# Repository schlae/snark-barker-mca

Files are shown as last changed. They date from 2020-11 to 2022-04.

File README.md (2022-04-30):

# Snark Barker MCA - A Sound Blaster Compatible for Micro Channel Computers!

Do you desperately want a sound card for playing games on your Micro Channel-based IBM PS/2 computer--a system designed for serious business purposes? Do you not want to pay the ludicrous auction prices for the rare Sound Blaster MCV cards? Well, despair no longer: the Snark Barker MCA has arrived!

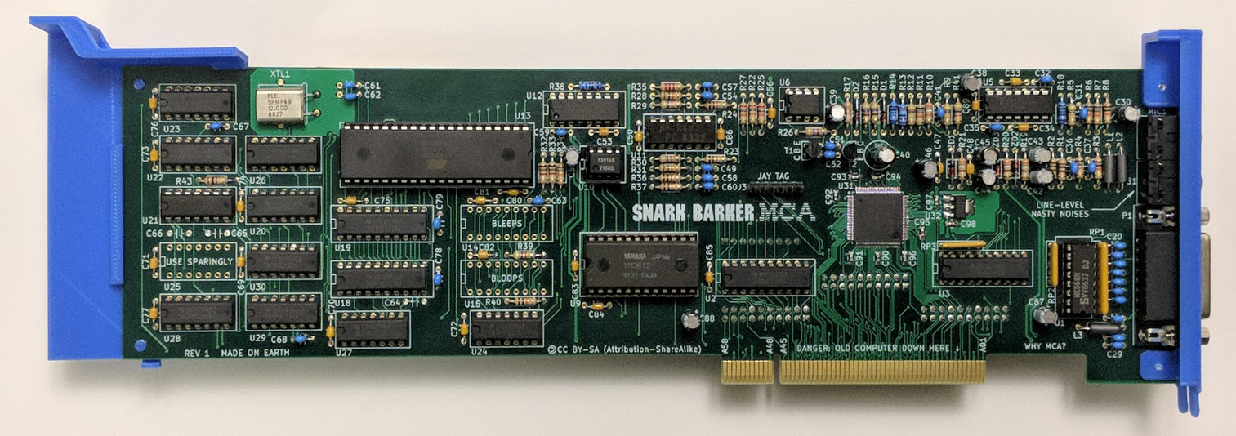
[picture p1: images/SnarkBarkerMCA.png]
Snark Barker MCA Photo


The Snark Barker MCA is a Sound Blaster-compatible sound card designed specifically for computers that use the Micro Channel bus. It supports Ad Lib synthesis, digital sound playback and recording, a standard PC joystick, and SB MIDI.

All of the components are readily available. In the bill of materials, Mouser part numbers are listed where available. The Yamaha synthesis chips may be obtained from a variety of sources in China, but they are not guaranteed to work, so I recommend getting 1 or 2 extras just in case. The same goes for the NE558. Note: A user reports that a Signetics NE558 with a date code of 8825VI that seems to be commonly available from China does not actually work. If you can't find any working 558 chips, try building [my replacement that uses four 555 chips](https://oshpark.com/shared_projects/zHGURt7g).

[Schematic](https://github.com/schlae/snark-barker-mca/blob/master/SnarkBarkerMCA.pdf)

[Bill of Materials](https://github.com/schlae/snark-barker-mca/blob/master/SnarkBarkerMCA.csv)

Please note that the 0.1" header pins are *not* listed on the BOM. They are standard breakaway headers. Headers J2, J4, J5, and J6 are optional and only useful for people who want to connect a logic analyzer to the bus for CPLD debugging.

The CMS chips U14 and U15 should not be installed since CMS functionality is not implemented at this time. Other devices listed as "DNI" are to be left empty with no component soldered in place.

Logic chips are all specified as AHCT, but ALS or ACT may also be used. Do not use LS or HCT devices, particularly for U2, since Micro Channel is a much faster bus than ISA and this logic is not quite fast enough to meet the timing margins. Bipolar families like F or S devices use excessive amounts of power but can be used in a pinch.

[Fab Files](https://github.com/schlae/snark-barker-mca/blob/master/fab/SnarkBarkerMCA-Rev2.zip)

## Fabrication Notes
This is a 4-layer board. The order of the two inner layers does not matter, but typically it goes F\_Cu, In1\_Cu, In2\_Cu, and B\_Cu. The board dimensions are 11.5 inches (292.1mm) by 3.475 inches (88.265mm).

When ordering the board, you **must** specify a card edge bevel of 20 degrees (details of the bevel are included in the Dwgs.User layer). This is **not** optional! The contacts in the Micro Channel socket are easily bent if you attempt to insert a card with no bevel. [Don't believe me? See this page.](https://www.ardent-tool.com/RS6000/RS6000_9-K.html#ECA265)

Ideally you should use selective gold plating (hard gold) for the edge fingers, but this can get expensive for small orders. ENIG will work but the gold will rub off fairly quickly.

For the soldermask color, pick whatever you want!

## Assembly Notes
I recommend soldering the CPLD (U31), the voltage regulator (U32), and the associated surface mount capacitors before you solder in the remaining components. You can do this by hand with a pencil iron or you can use a reflow process, but be aware that the board is too long to fit in the small hobbyist reflow ovens.

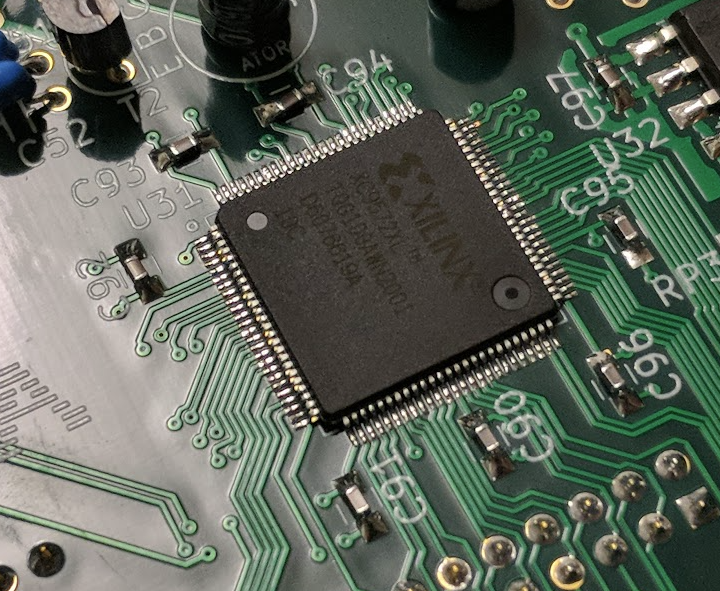
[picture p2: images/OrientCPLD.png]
Photo showing pin 1 alignment of CPLD


***Be sure the CPLD is soldered in the right way around! Compare it with my photo of the card to be sure you have it right!***

Inspect the CPLD's solder joints carefully with a microscope to make sure you don't have any bad connections or solder bridges. This can save you a lot of grief later on.

Install sockets for the Yamaha chips U9 and U10 in case you get one that doesn't work and need to replace it.

## Bracket
MCA brackets are no longer available. You have a few options:
- Remove the brackets from an existing card, like a token ring card or something common
- 3D print the bracket
- Use the card without a bracket at all

If you want to print your own brackets, here are STL files of the front panel bracket and the rear bracket.

[Front bracket](https://github.com/schlae/snark-barker-mca/blob/master/mech/SnarkBarkerMCABracket3D.STL)

[Rear bracket](https://github.com/schlae/snark-barker-mca/blob/master/mech/MCARearBracket.STL)

For best results, use high quality filament and a layer height of 0.16mm or better. If you print using blue filament, the color will match the original IBM brackets.

The front bracket should be oriented so that the front face of the bracket is facing towards the bed of the printer. The rear bracket should be oriented so its large flat spot (parallel to the card) faces the bed.

To secure the bracket to the card, you need two screws, and you have several options:
- 2-56 pan-head screws, 3/16" long, McMaster Carr 91772A076 or similar. These work but aren't the strongest.
- Number 2 thread forming screws, 3/16" long, McMaster Carr 99461A710 or similar. These should grip the plastic tightly (TODO: untested).
- There may be equivalent metric options but this requires experimentation. Please let me know if you find a fastener that works well.

## The Firmware
There are two ways to get a programmed 80C51 chip for the Snark Barker MCA. One is to purchase a SB 2.0 DSP chip from China and put it in a 44-PLCC to 40-DIP adapter. This works fine and provides the largest feature set.

Another option is to buy a blank Atmel 89S51 (as listed in the BOM) and program it with [this HEX file](https://github.com/schlae/snark-barker/blob/master/firmware/sb.hex).

## CPLD Notes
The Snark Barker MCA uses a CPLD (Complex Programmable Logic Device) to interface between the Micro Channel bus and the rest of the card's digital logic. This CPLD implements port IO, interrupts, DMA, and the card setup and POS (Programmable Option Select) systems.

The CPLD must be programmed with the bitstream before you can use the card.
[You can find the bitstream here.](https://github.com/schlae/snark-barker-mca/blob/master/verilog/mcsb.jed)

I've had good luck using the Linux command line program 'xc3sprog' with a FTDI FT2232H Mini Module [datasheet here](https://www.ftdichip.com/Support/Documents/DataSheets/Modules/DS_FT2232H_Mini_Module.pdf).

Wiring for the FT2232H mini module:

| Point 1 | Point 2 | Description |
| --- | --- | --- |
| CN2 pin 1  | CN2 pin 11 | V3V3 to VIO strap |
| CN3 pin 1  | CN3 pin 3 | VBUS to VCC strap |
| CN2 pin 3  | CN3 pin 12 | V3V3 to VIO strap (2) |
| CN2 pin 5  | JTAG cable pin 6 | V3V3 to Snark Barker (optional) |
| CN2 pin 2  | JTAG cable pin 5 | GND |
| CN2 pin 7  | JTAG cable pin 4 | AD0, aka TCK |
| CN2 pin 9  | JTAG cable pin 3 | AD2, aka TDO |
| CN2 pin 10 | JTAG cable pin 2 | AD1, aka TDI |
| CN2 pin 12 | JTAG cable pin 1 | AD3, aka TMS |

You need to provide external power to the Snark Barker through the 3.3V wire on the programming header. The optional wire does this, or you can use a bench supply.

I obtained xc3sprog [here](https://github.com/matrix-io/xc3sprog). You can compile and run this program on a Raspberry Pi to use the Pi GPIO lines instead of the FTDI mini module. In my case, I chose to patch it (TBD) to remove references to the Pi GPIO library and ran it on a regular Linux PC.

Using the FTDI mini module, programming is quite simple. Connect the cable to
the assembled Snark Barker board, then run the following command. You can do this with just the CPLD, programming header, and surface mount capacitors--there's no need to have any of the other components soldered in place for this step.

`xc3sprog -c ftdi -v mcadlib.jed`

If you run into issues with the cable not being detected, check your udev rules.
In theory you could run xc3sprog as root, but that's bad practice. ;)

### Building the CPLD Project
If you're feeling particularly masochistic, you can try building the CPLD project using the Xilinx ISE Webpack tools. Because the ISE Webpack only supports Ubuntu 14.7, it's simplest to run the program from a Docker container. I use [docker-xilinx](https://github.com/jimmo/docker-xilinx).

### How the CPLD Works
This isn't meant to be an exhaustive tutorial on how Micro Channel works ([you can find a tutorial here](https://github.com/schlae/mca-tutorial)). Functions provided by the CPLD include:
- Card setup and POS
- Address decoding logic
- Bus logic interface to the YM3812
- Wait state logic for the YM3812 interface
- Interrupt logic
- DMA state machine including arbitration logic

Each card implements several 8-bit registers (POS registers). Two of these registers are fixed and implement the 16-bit card ID value, which is how the BIOS and the reference disk software identify the card. The remaining POS registers can be used for any configuration-related function and are designed to replace configuration jumpers. The meanings of each register bit are up to the card designer, with the exception of a reserved bit that is used by the BIOS to enable or disable a card; this way, the BIOS can resolve conflicts automatically. Typically POS register bits control IO and memory address assignments, IRQ lines, and so forth.

The CPLD implements the two required ID registers as well as two additional POS registers. The first contains only a single bit -- the card enable signal. The second register controls the IO port setting, the IRQ and DMA channel settings, and the joystick port enable bit.

When you add a new card to a MCA bus system, the BIOS detects the new card and requires you to run the reference disk configuration program. This program searches for an ADF file associated with the new card. The ADF file is human-readable text that tells the BIOS which I/O address, IRQ, etc match up with each POS register bit. The reference disk program uses this information to find a configuration for all the cards in the computer so that none of them conflict with each other. When it's done, it writes the raw POS register values along with the card ID values to the battery-backed SRAM on the motherboard.

## Compatibility
The Snark Barker MCA has been tested on some models of PS/2. More to be added as
people provide test reports.

| Computer | Model | CPU | Compatible ? |
| --- | --- | --- | --- |
| IBM PS/2 Model 50Z | 8550-031 | 80286-10 | Yes |
| IBM PS/2 Model 55SX | 8555-X31 | 486SXLC2 | Yes |
| IBM PS/2 Model 56  | 9556-KB6 | 80486SLC2-50 | Partial(1) |
| IBM PS/2 Model 70  | 8570-E21 | 80386DX-16 | Yes |
| IBM PS/2 Model 70  | 8570-B21 | 80486DX2-50  | Yes(1) |
| IBM PS/2 Model P70 | 8573-061 | 80386DX-20 | Yes |
| IBM PS/2 Model P75 | 8573-401 | 486DX2-66 | Yes(5) |
| IBM PS/2 Model 80  | 8580-071 | 80386DX-16 | Yes(4) |
| IBM PS/2 Model 95  | 8595 | 486DX2-50 | Yes(1) |
| IBM PS/2 Model 95  | 9595 | Pentium-90 | Yes(3) |
| NCR System 3400 | 3433 | 486DX2-66 | Yes |
| NCR System 3400 | 3421 | 386SX-20 | Issues(2) |

Note 1: See the *Machine Specific Notes* section below for more details about this configuration.

Note 2: Some problems reported with the NCR 3421 possibly due to a conflict with the onboard SCSI. Further investigation is needed.

Note 3: The Ad Lib detection routine used by some games is reported not to work

Note 4: There is one report of the Plaid Bib (the ancestor to this card) behaving erratically in this model of PS/2. However I have not observed any issues with the Snark Barker MCA.

Note 5: Machine has LAN Adapter/A installed.

If you build the card and try it out, please let me know how it went. **Be sure to give me the full part number of your computer along with any installed options (3rd-party planar, memory cards, etc).** If you're located in Silicon Valley, you could also loan me (or even give me!) a computer not on this list and I will test for compatibility myself.

## Machine Specific Notes

### IBM PS/2 Model 56 486SLC2 (9556-KB6)
Configuration: No cards installed.

The joystick port conflicts with the SCSI host that is built into the planar and must be disabled.

### IBM PS/2 Model 70 486 (8570-B21)
The configuration tested included
- 8MB RAM (on the planar)
- ESDI hard drive with DOS 6.22 and Windows 3.11 installed
- Buslogic BT640A SCSI card
- IBM XGA-2 video card

Although not fully understood, this configuration experiences what appear to be IRQ conflicts. The Micro Channel bus allows IRQ sharing, but not all software supports this correctly, so it may be related to that. "Doom" only works when using IRQ2. A workaround is to replace the default DOS4GW DOS extender with the DOS32A extender; this allows IRQ5 and IRQ7 to work correctly.

The Windows Sound Blaster driver crashes unless it is replaced with the driver recommended by Creative Labs for the SB Pro MCV. "VDMAD.386" is in the SB Pro MCV driver pack.

```
Some PS/2 machines experience a "Bus timeout error" when running Windows
3.1 in enhanced mode.  If you have this problem, Copy VDMAD.386 to your 
WINDOWS\SYSTEM sub-directory and change the following line under the [386Enh]
section in your SYSTEM.INI file.
[386Enh]
;change this line
DEVICE=*VDMAD
;to this line
DEVICE=VDMAD.386
```

You can also fix it by first starting Windows in standard mode, `win /s`, exit, and then start Windows in enhanced mode `win` as you normally would.

### IBM PS/2 Model 95 486DX2-50 (8595)
The joystick seems to conflict with something else and the setup program turns it off.

Getting Doom to run is slightly tricky and requires a hack. It only worked when IRQ was set to 5 and DOS4GW was replaced with DOS32A, but this version doesn't properly initialize the sound card. The hack is this:
- Make a copy of DOOM.EXE: `copy doom.exe doom_p.exe`
- Apply the DOS32A patch: `sb /r doom_p.exe`
- Run the original first: `doom` and let it crash back to the DOS prompt.
- Run the patched executable: `doom_p`

## Installation
You will need the ADF (adapter description file) in order to set up the Snark Barker MCA on your Micro Channel computer.

[Snark Barker MCA ADF](https://github.com/schlae/snark-barker-mca/blob/master/@5085.ADF)

Place the file on a 3 1/2" floppy disk. After you install the card and boot
the computer, it will detect that a new card has been installed and prompt
you to insert the reference disk. Do this and follow the prompts. When the
setup utility asks you to insert the option disk, use the one that contains
the ADF file. After the setup utility configures the card, it will prompt
you to reboot the machine.

Plug your line-level audio amplifier input into the card's 3mm audio jack nearest the joystick port. The other audio jack above that one is for the microphone input.

Once that's finished, try out the Snark Barker MCA with your favorite game!

## Troubleshooting
Hoo boy, this one is a doozie. Someone once told me
> At Creative Labs tech support we would always get a sinking feeling whenever someone said they had a SoundBlaster MCA. Guaranteed at least a 45 minute call. Weekly average call time blown straight to hell.

Keep in mind that Micro Channel systems can be difficult to troubleshoot due to the large number of possible configurations and the varied implementations of the bus. Not all games will even work on some PS/2 systems even without a sound card!

Here are a few things to try out first before you starting really digging in:
- Is the CPLD soldered in correctly, with no solder bridges? Did you program it?
- Are there potentially bad or fake chips? Some users have reported issues with fake NE555s or fake 74ALS245 chips.
- Did you program and install the 8051 (DSP)?
- If the BIOS detects and installs the card, but you have issues with the audio, try removing all the expansion cards except for the Snark Barker
- Try running [SBDIAG](https://github.com/schlae/snark-barker/tree/master/sbdiag)

### Symptom-by-Symptom

**Computer will not boot at all, Computer boots but does not detect the card**

Suspect the CPLD. Check for bad solder joints. Is pin 1 oriented correctly? Compare it with the photo.

Did you use something other than a 74HCT245 or 74ALS245 for U2? Slower logic families can "crash the bus" and prevent the system from booting.

**Joystick doesn't function**

Is the joystick enabled? Run the setup program and navigate to "Change Configuration" and see if the joystick is on or off. The setup program may have turned it off due to a conflict with another card (Ethernet cards often like to use the joystick port location).

**No digitized sound. Digitized sounds play but are cut off**

It is possible that you have an IRQ conflict. Micro Channel allows for IRQ sharing and not all games support this correctly. Try changing the IRQ using the setup program's "Change Configuration" menu and see if that helps.

Since games implement Sound Blaster support in different ways, some programs may work and others may not!

**The card causes random errors with the hard disk, or other cards**

Do you have a legitimate 74ALS245, or is it fake? A user reported that swapping this part out with a legitimate one solved the problem for him.

### Troubleshooting for Engineers
If you have an HP logic analyzer, like a 1670 or 16700 series, you can connect three cables to the Snark Barker MCA using standard HP 01650-63203 termination adapters. The pin assignments are as follows:

| Pin |  J2 |  J4  |  J5 |
|-----|---|---|---|
| CLK | CMD | ADL  | PREEMPT  |
| D0  | BUSRESET  | A0 | DS16RTN  |
| D1  | M\_IO | A1 | CHRDYRTN |
| D2  | S0\_WRITE | A2 | MADE24 |
| D3  | S1\_READ  | A3 | CD\_DS16 |
| D4  | CD\_SETUP | A4 | TC |
| D5  | REFRESH | A5 | ARB/GNT  |
| D6  | CD\_SFDBK | A6 | CHCK |
| D7  | CD\_CHRDY | A7 | IRQ7 |
| D8  | DB0 | A8 | IRQ5 |
| D9  | DB1 | A9 | IRQ3 |
| D10 | DB2 | A10  | IRQ2 |
| D11 | DB3 | A11  | ARB3 |
| D12 | DB4 | A12  | ARB2 |
| D13 | DB5 | A13  | ARB1 |
| D14 | DB6 | A14  | ARB0 |
| D15 | DB7 | A15  | BURST |

Or, you can load [this configuration file](https://github.com/schlae/snark-barker-mca/blob/master/MCABASE._A) onto your HP analyzer and save a bunch of manual data entry. J2 goes to pod 1, J4 goes to pod 2, and J5 goes to pod 3.

An additional debug header, J6, brings out a few additional signals:

| Pin | J6 |
|-----|---|
| 1 | DBG1 (CPLD unassigned) |
| 2 | CLK\_14M318 (MCA bus clock) |
| 3 | DBG3 (CPLD unassigned) |
| 4 | DBG4 (CPLD unassigned) |
| 5 | DBG5 (CPLD unassigned) |
| 6 | DBG6 (CPLD unassigned) |
| 7 | DBG7 (CPLD unassigned) |
| 8 | SBHE (MCA bus signal) |
| 9 | GND |

## License
This work is licensed under a Creative Commons Attribution-ShareAlike 4.0
International License. See [https://creativecommons.org/licenses/by-sa/4.0/](https://creativecommons.org/licenses/by-sa/4.0/).

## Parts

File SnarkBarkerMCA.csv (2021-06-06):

Item | Qty | Reference(s) | Value | Footprint | Mouser
1 | 10 | C20, C21, C22, C23, C24, C25, C26, C27, C28, C29 | 0.01u | SoundBlaster:SB_C_DISC_200 | 810-FG28X7R1H103KNT0
2 | 11 | C30, C38, C39, C42, C43, C44, C45, C46, C55, C87, C88 | 10uF 16V | SoundBlaster:SB_C_RADIAL_75_150 | 667-ECA-1CM100I
3 | 7 | C31, C36, C37, C49, C54, C63, C78 | 1000p | SoundBlaster:SB_C_DISC_200 | 810-FG28X7R1H102KNT6
4 | 4 | C32, C35, C52, C79 | 330p | SoundBlaster:SB_C_DISC_200 | 810-FG28C0G1H331JNT6
5 | 24 | C33, C34, C47, C48, C50, C53, C56, C69, C70, C71, C72, C73, C74, C75, C76, C77, C80, C81, C82, C83, C84, C85, C86, C89 | 0.1u | SoundBlaster:SB_C_AXIAL_275 | 581-SA105E104M
6 | 1 | C40 | 100uF 16V | SoundBlaster:SB_C_RADIAL_100_320 | 667-ECA-1CM101I
7 | 2 | C41, C59 | 47p | SoundBlaster:SB_C_DISC_200 | 810-FG28C0G1H470JNT6
8 | 3 | C51, C58, C60 | 2200p | SoundBlaster:SB_C_DISC_200 | 810-FG28X7R1H222KNT6
9 | 1 | C57 | 4700p | SoundBlaster:SB_C_DISC_200 | 810-FG28C0G1H472JNT6
10 | 2 | C61, C62 | 30p | SoundBlaster:SB_C_DISC_200 | 810-FG28C0G1H270JNT6
11 | 3 | C64, C65, C66 | DNI | SoundBlaster:SB_C_DISC_200
12 | 1 | C67 | 470p | SoundBlaster:SB_C_DISC_200 | 810-FG28C0G1H471JNT6
13 | 1 | C68 | 270p | SoundBlaster:SB_C_DISC_200 | 810-FG28C0G1H271JNT0
14 | 9 | C90, C91, C92, C93, C94, C95, C96, C97, C98 | 1u | Passive:CAPC2012X55 | 187-CL21B105KAFNNNE
15 | 2 | D1, D2 | 1N4148 | SoundBlaster:SB_D_AXIAL_400 | 512-1N4148
16 | 2 | G1, G2 | logo1 | SoundBlasterMCA:Snark_BarkerMCA
17 | 1 | J1 | BUS_MCA | Conn:BUS_MCA
18 | 3 | J2, J4, J5 | HPLA_PORT | Pin_Headers:Pin_Header_Straight_2x10_Pitch2.54mm
19 | 1 | J3 | Conn_01x06 | Pin_Headers:Pin_Header_Straight_1x06_Pitch2.54mm
20 | 1 | J6 | DEBUG | Pin_Headers:Pin_Header_Straight_1x09_Pitch2.54mm
21 | 3 | L1, L2, L3 | BEAD | SoundBlaster:SB_L_AXIAL_500 | 623-2743004111
22 | 2 | MIC1, S1 | SJ1-3553NG | SoundBlaster:SB_SJ1-3553 | 490-SJ1-3553NG
23 | 1 | P1 | Joystick/MIDI | SoundBlaster:SB_DB15_152-3415 | 152-3415
24 | 2 | R1, R2 | 100 | SoundBlaster:SB_R_AXIAL_400 | 603-CFR-25JB-52-100R
25 | 9 | R3, R4, R8, R23, R24, R34, R36, R37, R40 | 10K | SoundBlaster:SB_R_AXIAL_400 | 603-CFR-25JB-52-10K
26 | 3 | R5, R9, R12 | 470K | SoundBlaster:SB_R_AXIAL_400 | 603-CFR-25JR-52470K
27 | 3 | R6, R7, R11 | 68K | SoundBlaster:SB_R_AXIAL_400 | 603-CFR-25JB-52-68K
28 | 1 | R10 | 39K | SoundBlaster:SB_R_AXIAL_400 | 603-CFR-25JB-52-39K
29 | 1 | R13 | 39.0K 1% | SoundBlaster:SB_R_AXIAL_400 | 603-MFR-25FBF52-39K
30 | 1 | R14 | 100.0K 1% | SoundBlaster:SB_R_AXIAL_400 | 603-MFR-25FBF52-100K
31 | 2 | R15, R16 | 470 | SoundBlaster:SB_R_AXIAL_400 | 603-CFR-25JB-52-470R
32 | 1 | R17 | 33K | SoundBlaster:SB_R_AXIAL_400 | 603-CFR-25JB-52-33K
33 | 1 | R18 | 1.5K 1% | SoundBlaster:SB_R_AXIAL_400 | 603-MFR-25FBF52-1K5
34 | 3 | R19, R20, R21 | 390 | SoundBlaster:SB_R_AXIAL_400 | 603-CFR-25JB-52-390R
35 | 3 | R22, R25, R27 | 27K | SoundBlaster:SB_R_AXIAL_400 | 603-CFR-25JB-52-27K
36 | 3 | R26, R39, R41 | 4.7K | SoundBlaster:SB_R_AXIAL_400 | 603-CFR-25JB-52-4K7
37 | 2 | R28, R31 | 15K | SoundBlaster:SB_R_AXIAL_400 | 603-CFR-25JB-52-15K
38 | 2 | R29, R30 | 47K | SoundBlaster:SB_R_AXIAL_400 | 603-CFR-25JB-52-47K
39 | 2 | R32, R33 | 1.5K | SoundBlaster:SB_R_AXIAL_400 | 603-CFR-25JB-52-1K5
40 | 1 | R35 | 2.2K | SoundBlaster:SB_R_AXIAL_400 | 603-CFR-25JB-52-2K2
41 | 1 | R38 | 2.70K 1% | SoundBlaster:SB_R_AXIAL_400 | 603-MFR-25FBF52-2K7
42 | 1 | R43 | 1K | SoundBlaster:SB_R_AXIAL_400 | 603-CFR-25JR-521K
43 | 1 | RP1 | 2.2K | SoundBlaster:SB_RP_4B | 652-4608X-AP2-222LF
44 | 2 | RP2, RP3 | 1K | SoundBlaster:SB_RP_4C | 652-4605X-AP1-102LF
45 | 2 | T1, T2 | 2N3904 | SoundBlaster:SB_TO92 | 833-2N3904-AP
46 | 1 | U1 | NE558 | SoundBlaster:SB_DIP16_300
47 | 1 | U2 | 74AHCT245 | SoundBlaster:SB_DIP20_300 | 595-SN74AHCT245N
48 | 1 | U3 | 74AHCT244 | SoundBlaster:SB_DIP20_300 | 595-SN74AHCT244N
49 | 1 | U5 | LM324 | SoundBlaster:SB_DIP14_300 | 926-LM324AN/NOPB
50 | 1 | U6 | LM393 | SoundBlaster:SB_DIP8_300 | 595-LM393P
51 | 1 | U9 | YM3812 | SoundBlaster:SB_DIP24_600
52 | 1 | U10 | YM3014B | SoundBlaster:SB_DIP8_300
53 | 1 | U11 | NJM3403A | SoundBlaster:SB_DIP14_300 | 513-NJM3403AD
54 | 1 | U12 | MC1408_DIP | SoundBlaster:SB_DIP16_300 | 926-DAC0808LCN/NOPB
55 | 1 | U13 | 805X | SoundBlaster:SB_DIP40_600 | 556-A89S51-24PU
56 | 2 | U14, U15 | SAA1099 | SoundBlaster:SB_DIP18_300
57 | 2 | U18, U19 | 74AHCT374 | SoundBlaster:SB_DIP20_300 | 595-SN74AHCT374N
58 | 4 | U20, U22, U23, U26 | 74AHCT74 | SoundBlaster:SB_DIP14_300 | 595-SN74AHCT74N
59 | 1 | U21 | 74AHCT125 | SoundBlaster:SB_DIP14_300 | 595-SN74AHCT125N
60 | 3 | U24, U27, U30 | 74AHCT32 | SoundBlaster:SB_DIP14_300 | 595-SN74AHCT32N
61 | 1 | U25 | SPARE | SoundBlaster:SB_DIP14_300
62 | 1 | U28 | 74AHCT08 | SoundBlaster:SB_DIP14_300 | 595-SN74AHCT08N
63 | 1 | U29 | 74AHCT14 | SoundBlaster:SB_DIP14_300 | 595-SN74AHCT14N
64 | 1 | U31 | XC9572XL-TQ100 | Active:TQFP50P1600X1600X140-100 | 217-9572XL-10TQG100C
65 | 1 | U32 | TC1262-3.3V | Active:SOT230P700X170-3 | 579-TC1262-3.3VDB
66 | 1 | XTL1 | 12MHz | SoundBlaster:SB_XTAL_HC49U_RA | 815-AB-12-B2
67 | 3 | ZD1, ZD2, ZD3 | 5.1V | SoundBlaster:SB_D_AXIAL_400_ALT | 78-1N5231B-TAP

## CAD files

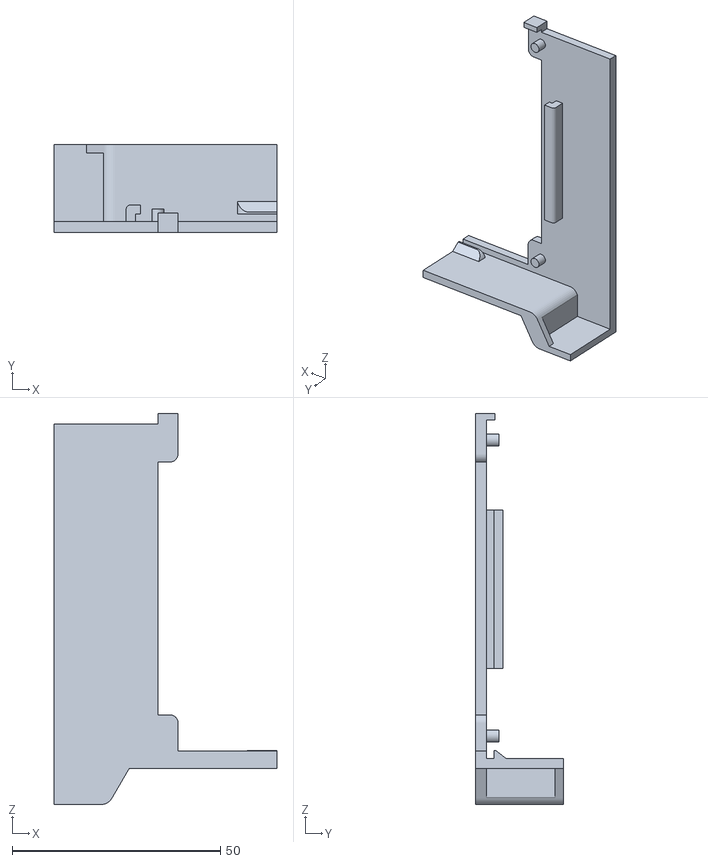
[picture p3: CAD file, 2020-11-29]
mech/MCARearBracket.STL
53.5 x 21.1 x 93.9

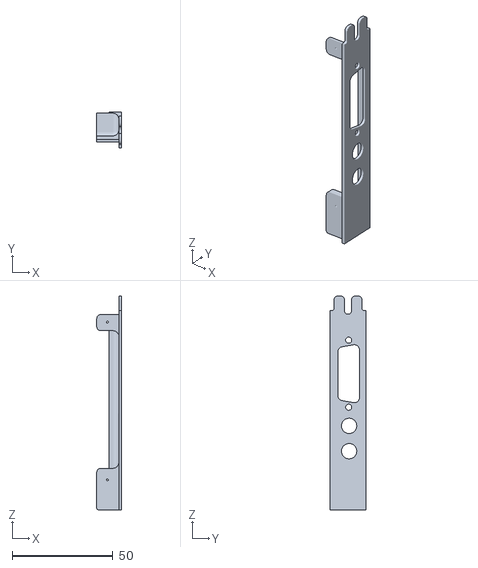
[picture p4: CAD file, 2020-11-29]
mech/SnarkBarkerMCABracket3D.STL
12.2 x 17.7 x 106.3

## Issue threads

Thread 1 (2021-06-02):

HCT a good choice?

vossi1, 2021-06-02:
Hello, this is not an issue, but a comment / question?

I built the plaidbib and it works perfectly with ALS and not with LS - like you recommended.

But for the snark barker you recommend HCT - but why? - HCT is slower than LS!
HC is slower than LS and HCT is even slower because of the TTL level adaption!

Timings from TI datasheets (load 45/50pF):
LS 245 has 8ns delay, 26ns enable, 15ns disable
HCT 245  15ns delay, 24ns enable, 24ns disable (at 5,0V)

I will use ALS 245 - like at the plaidbib - this is the best option and I think for all other chips is LS a good choice - better than slow HCTs.
I also tested successfully Fairchilds 74F245/04 in the plaidbib - very fast - but needs a lot of power.

schlae, 2021-06-06:
fixed

Closed 2021-06-06.

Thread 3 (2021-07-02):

Faster machines

vossi1, 2021-07-02:
Hi, this is not an issue!

I just read that the original SB MCV was designed for 286 / 386 machines only.
With faster machines it has problems with the bus and DMA.

You card runs in a 486/66 - so you built a much better SB MCA ;)
Has nobody tested it in a fast machine like a 9595 with P66 or P90 ?

The PlaidBib (without DMA) runs well in my P90 9595, I'm very curious if my Snark Barker MCA runs in my Server 95?
I have most critical chips as ALS here. But its a lot of work to build the card...

THANKS for designing this fantastic card!

schlae, 2021-07-02:
Give it a try and let me know if you get it working so I can add it to the compatibility list. Make sure you use the updated ADF file, which I changed recently to fix a bug.

vossi1, 2021-07-03:
Hi, first test in my 8570 with 16 MHz:
- FM works
- Digital sound works, also with DMA
- IRQ test OK
- joystick buttons ok
- MIDI Loop test ok
- Champ Kong, Shanghai 2 with digital sound ok
not good:
- Joystick analog input does not work, at first test there are zeros - I tried different NE558 - all are Signetics 1988 datecode - look original
- Microphone bar flickers full - no reaction of mic input visible - I tried different DAC0808 (china desoldered) - look original
- After some minutes testing or when simply copying files to hd, I get critical error when writing to harddisk from dos in the upper left corner!

Any hints for me?

schlae, 2021-07-03:
Try swapping out U2 and U3. You could try a part from the AHCT family or the F family. The mic input requires a microphone that can provide its own bias voltage (for the electret type, it should have a battery inside it) or a dynamic mic that doesn't need a battery.

vossi1, 2021-07-04:
Hi,
the harddisk errors were cause by a chinese 74ALS245 fake (I think it's only a LS). With a real ALS no problems anymore.
The mic input error was easy to find: 390k instead of 39k soldered ;)
Swapping the 244 to a real old 74F244 doens't help with the joystick port. I ordered Philips NE558's - and hope that's the problem.
The card runs nice in my 9595 P90 !!!!! - I had to change my Etherlink resources IRQ 5 to 12 and address 200 to 600.
I just played duke 3D with sb+adlib music. The sound setup doesn't detects the adlib - but the game works with fm-sound.
Pinball Dreams 1 soundsetup crashes. I manually selected sblaster - but no sound in the game.

I use most ALS chips. Only the 74, 08 and 14 are LS types.

I will check more....

vossi1, 2021-07-08:
Hello, the game port works now!
I first got five really good looking Signetics NE558 timers with datecode 8825VI from china.
I successfully tested them on a breadboard with a LED at the output and 100uF/10k for a 1 second pulse.

Now I desoldered a Signetics 558 from an ESS audio drive ISA card and tested at also at the breadboard - it does exactly the same.
Finally I tested this 558 it in the snark barker mca - works perfectly.

So it seems that the chines built bad fakes that are partially working.
-> Be AWARE guys - these 558 from 88 are widely spreaded in the world offers at ebay, Aliexpress... !!!

Thanks again, TUBETIME, for the good work!

schlae, 2021-07-08:
Great news! I've updated the readme with the information about the fake chips and the machines that you've tested your card in.

mlyle, 2021-08-02:
@Vossi1 When you were having disk IO issues, what was that like?  I've opened #7 because of similar problems (many programs generate an NMI/exit, and then the hard disk doesn't work afterwards, and then the system fails POST with 00010300 until power cycled).

vossi1, 2021-08-05:
> @vossi1 When you were having disk IO issues, what was that like? I've opened #7 because of similar problems (many programs generate an NMI/exit, and then the hard disk doesn't work afterwards, and then the system fails POST with 00010300 until power cycled).

As you read in my posts the harddisk problems were also present without the snark barker in the slot. Thats a SmartDrive problem with pcdos4.

Closed 2021-07-08.

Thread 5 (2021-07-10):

Compatibility Model 70 Type1, Model 95 P90

vossi1, 2021-07-10:
Hi,
I just tested more and found out this:
- The harddrive issues in model 70 are caused by smartdrive's write cache. With only read cache enabled - no problems anymore. You can delete harddisk problems with model 70 and sb mca.
- In model 70/16MHz the sb mcv runs perfectly. test-sbc from the sb mcv-disk and test-sbc from the sb 2.0 disk works. Adlib sound is detected by games like Prince of Persia, Arkanoid 2, Shanghai II. SB is also detected in some tested games.
- In model 95 test-sbc of sb-mcv and sb 2.0 is not able to play fm-sound! Also some games don't detect the adlib card. You sbdiag and most games play fm-sound properly. Soundblaster is also detected by a lot of games.
- Windows 3.1 runs in both machines with the sb mca but you have to add MCADMA=off to [386enh] in system.ini. This is a common problem also with the real sb mcv. digital sound in WIn 3.1 works, but it hangs when trying to play a .mid file with the Windows media-player.
- I tested with all chips as ALS, but no better compatibility. So I think its ok to use ALS (or F, maybe ACT, ABT) only for the 244, 245 and the 374's (for me LS374 also works - but for safety take ALS). You should also use ALS for the 32 in U24 (joystick CS) - this is also a fix for the real sb mcv. All other chips are ok as LS. I haven't tested HCT - but HCT is much slower than LS - so I wouldn't use them.

QUESTION: SB MCA 1.0 or 2.0 ???
Many games like Doom, Doom2, Doom Ultimate, Pinball Dreams 1 have problems with the Sound Blaster 1 (maybe because it does only 22kHz?) - these games have also probs with the snark barker mca.
Is the snark barker mca with DSP 2.02 (from sb 2) a soundblaster 1 or 2 ??? - does it 22kHz or 44kHz?
Or is for 44kHz a different hardware needed?

Vossi

elosha, 2021-07-10:
SB 1.0 vs 2.0:
2.0 mainly was a firmware upgrade that added a new 44KHz transfer/playback mode which operates at the boundaries of SB hardware. So DSP 2.0 makes any Snark Barker a SB2.

Other workarounds:
Disabling write caching or DMA appears like quite an impact for me, or did I misunderstand?

vossi1, 2021-07-10:
Disabling write cache has nothing to do with the snark barker. I thought this first but the error also occurs without the sb when copying many files from floppy to HD. Maybe the harddisk has a problem. It's only a problem in this model 70.
Or it's the software combination of IBM DOS4 with smartdrive from Windows 3.1
DOS4 has no smartdrive included. I will try to use dos 6 on the 70.

About MCADMA=off I read at the same source like you ;) It works in both machines.

vossi1, 2021-07-11:
WIndows 3.1 runs with DMA now on model 70 and 95!
You have to take the VDMAD.386 from the SBProMCV drivers and copy it to the windows 3.1/system directory.
In the system.ini [386enh] area you have to change DEVICE=*VDMAD to DEVICE=VDMAD.386 - that's it ;)

Seems like the MCADMA=off is really only a workaround neccessary for the old dma-controller in model 57.

BTW: I just read that the original sb mcv has sound blaster 1 hardware without cms and amp but already with DSP 2.0:
https://ardent-tool.com/sound/Sound_Blaster.html

vossi1, 2021-07-15:
Hi, I just found this:
Owners of previous revision Sound Blaster boards could upgrade their board by purchasing the V2.00 DSP chip from Creative Labs, and swapping the older DSP V1.0x with the newer replacement. The upgraded board gained the auto-init DMA and new MIDI capabilities of the Sound Blaster 2.0 but not the expanded sampling rates.

Question: What sampling rate is with the Snark Barker MCA possible: 22kHz or 44kHz ? If it has only 22kHz (also with DSP 2.02) this is maybe the problem with some games like doom?

schlae, 2021-07-15:
the sample rate is controlled purely by the DSP, and with either the Chinese clone firmware or the genuine DSP 2.02, it should work fine at 44KHz.

vossi1, 2021-07-19:
I got a bench of different real old ALS chips from TI and Motorola and tested a snark barker with it in my 9595.
Sadly no difference:
TEST-SBC of SB1 and SB2 driver disks does not play FM-sound.
Some games doesn't detect an adlib soundcard for music.
Doom doesn't run with SB digital sound.

So I think it's more a problem of the 9595...
Also Flight sim 5, Prince of Persia and Pinball dreams1  doesn't run on the 9595. PS/2's are not standard 100% compatible dos-pc's!

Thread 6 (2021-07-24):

NE558 Fakes

vossi1, 2021-07-24:
Hi, sadly I just got the next batch of non working NE558 :(
My desoldered SEC KA558 from a ESS Audio Card works perfectly...

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

vossi1, 2021-07-25:
OK, I tested all 558's in my ESS audio drive in an ISA model 30/286 - all are ok!
So we have a bug!

Why only the SEC KA558B works and all other original Signetics 558 doesn't work in the Snark Barker MCA?
Is there a difference in the design?
I tested the SB MCV in my 70/16MHz and in the 95/P90. In both machines only the Samsung 558 works.

I will check the circuit design on my SB 2.0 ISA - and check how they use the 558...

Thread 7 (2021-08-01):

Compatibility Model 57 486SLC2

mlyle, 2021-08-01:
Hi all-- first, I actually have the TexElec hardware, but from what I understand, on the bus it should be the same.

It disables the joystick port (like the model 56) because of conflicts with SCSI on planar.  But the big issue is, PCM sound seems to intermittently cause NMIs, after which the SCSI goes away and doesn't answer requests until a power cycle (I get a 0010300 on the next POST if I reboot without a power cycle).  I've tried every combination of DMA channel and IRQ.

I can reproduce this by going into FastTracker 2's config and toggling the sound back and forth between "Sound Blaster" to "Speaker".  It usually manifests within 5-6 cycles, and always in less than 40.

I've tried with minimal configurations of jemmex / himem, getting rid of disk caching and all exotic things.

Adlib emulation, etc, all seems fine (haven't tried MIDI yet).  Seems like it is likely something with DMA?

mlyle, 2021-08-01:
Also, one more note: I had had a Token Ring card in an expansion slot, and it seemed like after removing it that things became a lot more reliable, taking about twice as long to trigger... so something electrical / bus loading / etc can't be ruled out.

schlae, 2021-08-01:
have you tried testing it using SBDIAG?

mlyle, 2021-08-02:
Yes.  SBDIAG is completely reliable on the tests I can do without scoping it-- DMA sine wave, play digital audio, etc (and the OPL3 tests, etc.  I can even hold down 6 to get in and out of the sine wave rapidly without issue.

I'm looking for a simpler repro.  Original SB stuff-- sbdiag, sbtalker, etc, seems fine.

FastTracker seems reliable as long as the card is not reinited.  It tends to pop and then hang in the same way between Wolf3D levels (perhaps something is being reinit'd here?)  And then after ctrl-alt-del, I get the logic board error.

mlyle, 2021-08-02:
Just one more new observation:  After I get things broken, sometimes I can exit to the DOS prompt.  Things attached to SCSI don't work (general failure reading...). ... but also the *floppy* surprisingly does not work.  It spins, etc, but again, "general failure".  And then 00010300 on reboot.

schlae, 2021-08-02:
that seems to be good news and bad news. the good news is that the card works. the bad news is that those programs aren't really compatible. the main reason is that MCA allows for IRQ sharing, and the BIOS will configure cards to share IRQs. but not all games will properly chain the IRQ handler for the sound card, which leads to compatibility issues.

mlyle, 2021-08-02:
I understand IRQ chaining.  It seems to me like this must be something more:

* The problem is persistent post-reset.  Whatever bad thing happens, causes the machine to fail the abbreviated reset-self test until power is cycled.
* No choice of interrupt works.  My preferred IRQ 7 has no conflict-- the parallel port is disabled.  I have also tried every combination of interrupt.

mlyle, 2021-08-02:
Failing item in POST is 4D-- which I believe is checking the timer interrupt.

mlyle, 2021-08-02:
More info:  It looks like something shows up in the system error log viewed from the reference disk.

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

I have one DMA arbitration timeout per crash... on DMA1 when using DMA1 and on DMA03 when using DMA3.

Doesn't this mean we're not hitting timing for DMA arbitration?  This likely takes simultaneous I/O and sound to get to fail, which explains why I can't make it happen in SBDIAG, etc.

mlyle, 2021-08-02:
Note: I have a Snark Barker MCA on the way from Monotech, as well as some blank boards, so I can compare soon.  Also will be nice to have schematics / can hook up a logic analyzer if necessary.

schlae, 2021-08-02:
hmm, that does sound like an error in the DMA arbitration state machine.

mlyle, 2021-08-02:
For kicks, I bumped SCSI to DMA1 and the SB to DMA3, and it's no better (possibly worse, but sample size is small).

mlyle, 2021-08-10:
One thing I see, peeking at the verilog-- it doesn't look like the preempt signal is handled as an input.

If another card or the host raises preempt, we're supposed to vacate the bus within 7.8 microseconds (78 cycles?).  We're a higher DMA priority than the SCSI, but there's a "fairness" feature where it can decide to preempt us after awhile and we're supposed to stay inactive until preempt and status falls.    pg 29-30, "Programmable Arbitration and the Inactive State", IBM PS/2 Hardware Interface Technical Ref.

mlyle, 2021-08-10:
Just an add'l heads up: my ETA on the Monotech card is Aug 16th.  Unfortunately, I will be very busy for that week and won't be able to get to attaching a logic analyzer until a week or two later.  The existing card I could JTAG if we come up with a new bitstream before then, but it doesn't have the signals broken out for analysis.

I'm hoping CHCK# gets asserted on a DMA timeout (an NMI pops, so this seems likely).  In which case I can see whether PREEMPT fiddliness happens immediately before CHCK# and what the DMA signals looks like for a number of cycles before then.

mlyle, 2021-08-10:
Ehhh.. now I see we don't burst, so I'm confused.

schlae, 2021-08-10:
Yep, preempting of an ongoing DMA cycle implies burst mode. An individual transfer is "atomic" but a burst operation isn't necessarily (iirc there is a way to do atomic burst operations, limited by fairness). I've noticed this by watching the model 95 doing DMA with the SCSI controller, and I've seen burst operations interrupted partway through, then continue after the interruption. It's all part of the "joy" that is MCA.

mlyle, 2021-08-10:
I don't really know much about MCA.  Does it strictly imply burst?  Could we just hold the channel without bursting and then be expected to obey preemption?  It looks like from spec this is true, but I don't know if in practice Snark could do this.

mlyle, 2021-08-12:
Received Monotech Snark Barker.

* Workmanship is a little questionable; lots of bypass caps standing / bent over on 1cm+ of leads
* All the parts are 74HCT* series logic :( vs. ACT for Resound
* The problem seems to repro the same, but I'm bummed that there's the additional confound of borderline-speed logic.
* Will be soldering down headers for logic analyzer tomorrow.  It's a little sad to have the legend on the bottom where I can't see, but it looks like most of what I want is on the first few pins of J5.

mlyle, 2021-08-12:
Nevermind.  I think the Monotech S.B. killed my PS/2.  After the latest crash I get video errors on POST and it comes up in monochrome.

mlyle, 2021-08-13:
OK, I'm about 45 minutes into debugging this.  Having trouble figuring out how to get my LA to trigger on the correct condition.

After failure, AR1/AR2/AR3 get stuck low and never rise.  AR/GN# is high.

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

Having a lot of trouble writing a trigger condition to trigger e.g. after AR1 has been low for 20 microseconds

mlyle, 2021-08-13:
Here's the failure.  It looks like we're granted, do nothing, and then are preempted... and then timeout.  More investigation needed.

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

mlyle, 2021-08-13:
Going to probe CD_SFDBK# and CMD#

mlyle, 2021-08-13:
Nothing too exciting there:
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

mlyle, 2021-08-13:
What happens if dreq falls as we're granted?  dreq_gated will be false, so we won't let go, right?

    always @ (posedge arb_grant_l or posedge chreset) begin
	if (chreset) begin
		dmacycle <= 1'b0;
	end else begin
		// Is this a DMA cycle we requested?
		dmacycle <= dreq_gated;
	end
    end

mlyle, 2021-08-13:
No... I misread that.  Probing S1R# and M/IO#

mlyle, 2021-08-13:
note cdfb was misconnected in previous traces

mlyle, 2021-08-13:
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

On the left, an "OK DMA".  On the right, a bad one where we never do anything, are preempted, and eventually time out.

mlyle, 2021-08-13:
Closeup of OK DMA

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

Closeup of bad DMA

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

mlyle, 2021-08-13:
I don't really know the sound blaster innards.  I'm guessing DMA gets cancelled right as the card "wins".  Then the arbitrator gets angry with us holding the bus and not doing anything.
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
mlyle, 2021-08-13:
It's unclear to me that there's any actual way to fix this.  We don't have a way to relinquish the arbitration grant-- the central arbiter does it when the burst, command, and status bits do the right thing.... and the DMA controller will not do it because it is disabled.  CMD needs to toggle at least once.

We shouldn't drive the address lines, because we could end up fighting with the DMA controller if it's actually enabled.

I guess we could generate a fake busmaster-read without driving the address lines, which would hopefully be relatively harmless and tell the central arbiter to take the bus away from us.

schlae, 2021-08-14:
or just time out and release the bus arbitration lines. then try again with the DMA operation later.

mlyle, 2021-08-14:
Does the arbiter know to re-arbitrate then?  The manual doesn't make it sound like it (and makes it sound like it may even be holding them low.

mlyle, 2021-08-14:
Like, I'm not the expert on this at all...  But this language:

> The central arbiter recognizes an end-of-transfer when both status
signals (-so and -51), -BURST, and -CMD are inactive. Control of the
channel is then transferred to the next higher priority device or to the
system microprocessor by default.

Makes it sound like ARB/GNT# will go high only when posedge CMD and those other conditions are met (S0#/S1#, BURST# all high).

mlyle, 2021-08-14:
My proposal:

* The maximum DMA cycle I've seen to the card takes 1.3us
* 7.8 us is a value where timeouts *could* occur, even though it seems like a lot of margin.
* I propose adding a 6 bit timer, reset when not granted and counting 14.318MHz during grant cycles.
* When timer is 11111x, drive S1R low (140 ns pulse, after 4330 ns).

I'm hoping the latter is enough because the Sept 1990 manual describes an "aborted cycle" with a minimum Sx width (T2A) of 85ns, and the arbiter is documented to listen to Sx.  But if it doesn't work, my next plan would be

* When timer is 1110xx (after 3.9 us) or 11110x, drive, drive S1R low.  When timer is 11111x, drive CMD low.

And if that's not enough, it gets gory to need to generate address latch, etc, too.

mlyle, 2021-08-15:
I've had only a short time to play, but I'm having difficulty adding a timer and fitting in the device.  Cleverness will be required.

mlyle, 2021-08-15:
This is what I tried:

```verilog
inout s1_r_l,
...
reg [5:0] dma_timeout_tmr;
reg dummy_read_cycle;
...

// I am concerned about the mingling of clk14 and other signals that aren't synchronous
// to it without any synchronizer-- metastability, but I am mimicking the design pattern
// seen above with the timeout timer
always @ (posedge clk14) begin
	if (dma_selected) begin
		dma_timeout_tmr <= dma_timeout_tmr + 1;
	end else begin

		dma_timeout_tmr <= 5'b00000;
	end

	if (dma_timeout_tmr[5:1] == 5'b11110) begin
		dummy_read_cycle <= 1'b1;
	end else begin
		dummy_read_cycle <= 1'b0;
	end
end

assign s1_r_l = (dummy_read_cycle & arb_won) ? 1'b0 : 1'bZ;
```

mlyle, 2021-08-15:
Looks like others are seeing the exact same issue:

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

mlyle, 2021-08-15:
Yup-- I'm not going to get to really look at this until school is underway.  Probably the most logical approach that I can see would be to combine the two timers.   It could count all the way up and then stop at 63 instead of 34 or whatever.  It's delicate, though.

@schlae Any help you can offer would be greatly appreciated.  I can probably find time to test bitstreams in this next couple of weeks, but there's no time to *think*.  Thank you for everything-- your advice on this and the S.B. design.

schlae, 2021-08-16:
I'll have to spend some time thinking about it. Another possibility is to add an external RC delay although that is less precise.

mlyle, 2021-08-17:
Yup-- that's possible, but there's a lot of cards out here at this point.  On Snark Barker it would be OK because it could plug into the CPLD header, but on the Resound card it'd be a real pain.

I think it's going to be a little clever/hacky no matter what.

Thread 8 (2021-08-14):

DREQ is treated as level triggered, but card only produces a short pulse.

mlyle, 2021-08-14:
(And DREQ rises again before anything with the DMA has completed).

Shouldn't we actually latch a "pending DMA" and then clear it when we've won arbitration?  Otherwise, if there's an arbitration happening when the DREQ is asserted, we could miss the DMA request entirely because DREQ_GATED never rises.

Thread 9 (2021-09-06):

Win95 crash

siordon, 2021-09-06:
Has the Snark Barker MCA been tested on Windows 95?
I have a model 56 (configured with joystick port disabled), and Win95 causes the whole system to lock if the Sound Blaster device is enabled. There are no conflicts, and everything checks out ok with SBDIAG.  Most games I've tested (DOS) work fine, except for Epic Pinball which also causes the system to lock up.
Any suggestions?

siordon, 2021-09-06:
More data points - may be port related.
Syndicate
- Works with no port specified, with sound.  (Eg: main /iirq5 /idma1)
- Works with wrong port specified, no sound. (Eg: main /iirq5 /idma1 /iio240)
- Crashes with correct port specified. (Eg: main /iirq5 /idma1 /iio220)
- If card changed to port 240, I get no sound even with the first example

Epic Pinball
- Works with incorrect port specified, reverts to PC speaker
- Crashes with correct port specified (tried with both 220 and 240)

Win95
- Yellow exclamation mark if configured with incorrect port, but at least it doesn't crash.

vossi1, 2021-09-06:
Hi,
1. Epic Pinball runs perfectly in my 9595 with P90 Complex. In the setup I selected SB Mono and use parameters from SoundBlaster Variable.
2. I tried to install Windows 95 (before I had the Snark Barker) from harddisk like I read in the web. But I had no success and give up. The cdrom does not work because it's a special scsi cdrom from IBM - that's why it's only possible from HD.

siordon, 2021-09-07:
Thanks.
1. Epic Pinball setup is correct (SB Mono, matches setup/blaster environment variable).  When I run it, there is a brief "click" from the speakers (the usual sound often made when a game initialises a soundcard), the internal speaker beeps, and the computer freezes completely (power button required)
2. Mine has no CDROM. I installed Win95 by copying the files to the hard drive from an external parallel port CDROM drive. Win95 installed just fine. However with the SB installed, enabled, and configured correctly, the system locks up completely when trying to start Windows (or, if the SB device is disabled, when enabling the device)

holzachr, 2021-11-28:
Hi,
I'm having the same issue with Win95(B) on my 9576i with Lacuna planar and 486DX2/66. Computer locks up when enabling the device, or while booting.
SBDIAG is fine, and sound comes out of DOS DOOM with IRQ 2, but crashes with any other IRQ.
Tried all possible IO/IRQ/DMA settings, but Win95 keeps locking up.
That's strange, as I am 100 % sure I had a similar machine (9577i Lacuna, so it's the same planar) running fine with the SB **Pro** MCV a few years ago.
Unfortunately, there's no updated drivers out there for Win95, apart from the builtin ones MS delivered with Windows, so nothing one could try on that front.

holzachr, 2021-11-29:
BTW, it's a card built by Monotech, and it's running fine under WfW 3.11.

vossi1, 2022-02-25:
Hi, I just installed win95c on my 9595 P66. Win 95 hangs after MSSBLST.VXD loading.
Is there really no other win95 driver?
Maybe I will try win98...

holzachr, 2022-03-09:
I heard, the trick is installing the Windows 3.x driver under 95, but didn't verify it myself yet.

vossi1, 2022-03-09:
Yes, the Win3.1 driver works for all software that uses the windows driver.
You have to install the oemsetup.inf from the sbmcv/win31 folder vie hardware/manual/disk.
Only install the second driver it offers (wave & midi). This is the digital audio and midi-out driver. It does not appear in the controlpanel/system, but you find it in controlpanel/multimedia (sb 1.5 wave). You can also install directX8 if you have a pentium. dxdiag shows the driver also.
Do NOT install the first driver (sb midi synth). It freezes the machine instantly if at access. So you have sadly no midi music via the OPL chip. I tried the adlib opl-driver - but it also doesnt work.
Some games have their own driver (ex. 3d ultrapinball) - they have sadly no sound with the snark barker.
PS: With a 486 you can only use Direct x 6.1.
PS2: I installed the microsoft joystick driver from the hardware list - seems to work. But I have no working 558 in this card - I hope the next batch arrives and is finally ok.

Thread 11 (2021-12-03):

Conflict with SCSI card

VargSilvermane, 2021-12-03:
I have a IBM P70 with a future domain MCS-700 SCSI that refuses to play nice with either of my MCA sound cards. I get a conflict on the i/o address line and no combination of tweaking the address for either card will clear it.

Info follows:
1. I have both the reference snark barker and the resound new wave version. Both test out on this system just fine.
2. ESDI drive was removed from system(though temporarily replaced to verify sounds cards)
3. model of SCSI is Future domain MCS-700/SCSI-2 with TMC-18C50 chipset and IBM bios 1.01.
4. adapters conflict on a range of 140-170 for the SCSI with the sound cards 220-260. (How?)
5. card in the highest number slot ends up being the one showing the conflict (asterisks) and subsequently the card that ends up being disabled

Any help would greatly be appreciated.

schlae, 2021-12-03:
There may be another card/resource in the system that can either use 140-170 or 220-260, meaning that you can't have the combination of the 3 devices in the system at the same time. The setup utility may be able to give you that information (there's a menu called View Configuration, IIRC).

VargSilvermane, 2021-12-03:
So set configuration and view configuration are basically the same screen. Why IBM decided to have a redundant screen with one being read-only i have no idea. That being said I can remove either card and the system functions correctly. This is even with no changes to the respective cards configuration. The ref disk just seems to think they are using the same resources for some reason. I'm wondering if this is an instance of false identification of a conflict, though i have no idea how to override it. The system just allows the first card detected(slot 1) to remain active while it disables the second(slot 2). IE if you were to swap the cards around it would always choose the second slot to disable.

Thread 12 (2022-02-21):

D87c51 does not work!

vossi1, 2022-02-21:
Hi, i just tested some intel D87c51 mc's with dsp2. 0 in two snark barkers and they dont work.
No respond of any dsp test.

My at89s51 work great.

Have you an idea why?
Shouldn't the also run in the sb?

Christian

vossi1, 2022-02-24:
Negative Update:

I got intel TD87C51, D8751-H and 3x Signetics/Philips SC87C51CCF40.
All are fully 80c51 compatible!

None of them works in the SB MVC. Get DSP ID gives -1.255

But why???

schlae, 2022-02-24:
Are you using sbdiag for that test? It will likely take some more detective work to track this down. Do you have a logic analyzer?

vossi1, 2022-02-24:
I use sbdiag and test.sbc also doesn't find the card at 220.
OPL2 sound in Arkanoid2 works.

Have you modified the dsp2.02 software? Or ist it the original creative 80c51 file?

I have a LA. What signals do you need to check?

schlae, 2022-02-24:
Look at ISA_RD, ISA_WR, DSP_WRITE, DSP_READ to get an idea of the timing of the mailbox reads and writes. I have a feeling the issue is with the mailbox (U19/U18) or possibly the associated buffer U2. What logic family did you use for those chips? They should be fast, like AHCT, ACT, or F.

vossi1, 2022-02-24:
We previously talked about the TTL-speed ;)
I have only ALS chips.

I just looked in the schematics and the d87c51 intel datasheet. EA/VPP should be +5V and ALE/Prog ans PSEN should be open - so all ok - even for an old 87c51.
What chip does creative used on a sb 1.0? I sadly have only some 2.0 with plcc chips.

elosha, 2022-07-06:
@schlae AT89S51 is getting difficult to order. Which MCS-51 devices have you found to work in SB/SB-MCA?

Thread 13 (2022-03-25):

Use of MicroChannel audio feature

elosha, 2022-03-25:
MCA seems to include an audio bus: Signals AUDIO_GND (contact B1) and AUDIO (contact B2).

1. However these are not used by SB MCA, what is the reason?
2. Could the PCB be patched to connect them, i.e. to use PC Speaker for sound output?

Thanks :)

schlae, 2022-03-25:
I have not tried it, but in theory it is possible to do. You have to use a series resistor since the audio signal line is an op-amp summing junction. Conversely, you can also go the other way so that the SB can mix the PC speaker sound in and direct it to the line output jack. The main reason I didn't add this feature is that I have no adjustable mixing chip on this design.

elosha, 2022-03-26:
Thanks for the info! That's cool! 👍

On my wishlist for a possible future rev:

It would be nice if we could have a trimmer + signal routing jumper, or at least a MCA audio bus pinheader and also audio in/out pinheaders (like SoundGalaxy). One could also attach a CD-ROM audio cable then.

Sure it wouldn't be actively mixable, but a simple trimmer for one-time adjusting audio levels would theoretically be fine.

pleonard212, 2024-06-29:
I noticed the same feature in the MCA spec and got curious about it (including why no MCA sound cards ever seemed to use it). It looks like it was mainly intended for modem use — sending the initial squeaks and squawks to the PS/2’s speaker until a successful connection was made.

Having said that it would be very interesting to see how it functioned in a sound card context!

schlae, 2024-06-29:
probably because the internal speaker is not very good. the audio pin is pretty simple, it goes to a 620 ohm resistor to ground and then has a series coupling capacitor and series resistor to the input of an LM386 audio amp. the resistor helps mix this signal with the PC speaker signal.

you can either drive the pin with a buffer or you can listen to the pin with an amplifier. there might be a way to do both at once, if the audio path from the card ties to the pin before the final output amplifier stage.

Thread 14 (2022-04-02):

Not an issue - I finally found really working good NE558 !!!

vossi1, 2022-04-02:
Hi, after 4 non working versions of 558 (3x old Signetics), I finally found really good KA558B at ebay:
https://www.ebay.de/itm/402466140256

All five KA558B run perfctly in my P90 ;)
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

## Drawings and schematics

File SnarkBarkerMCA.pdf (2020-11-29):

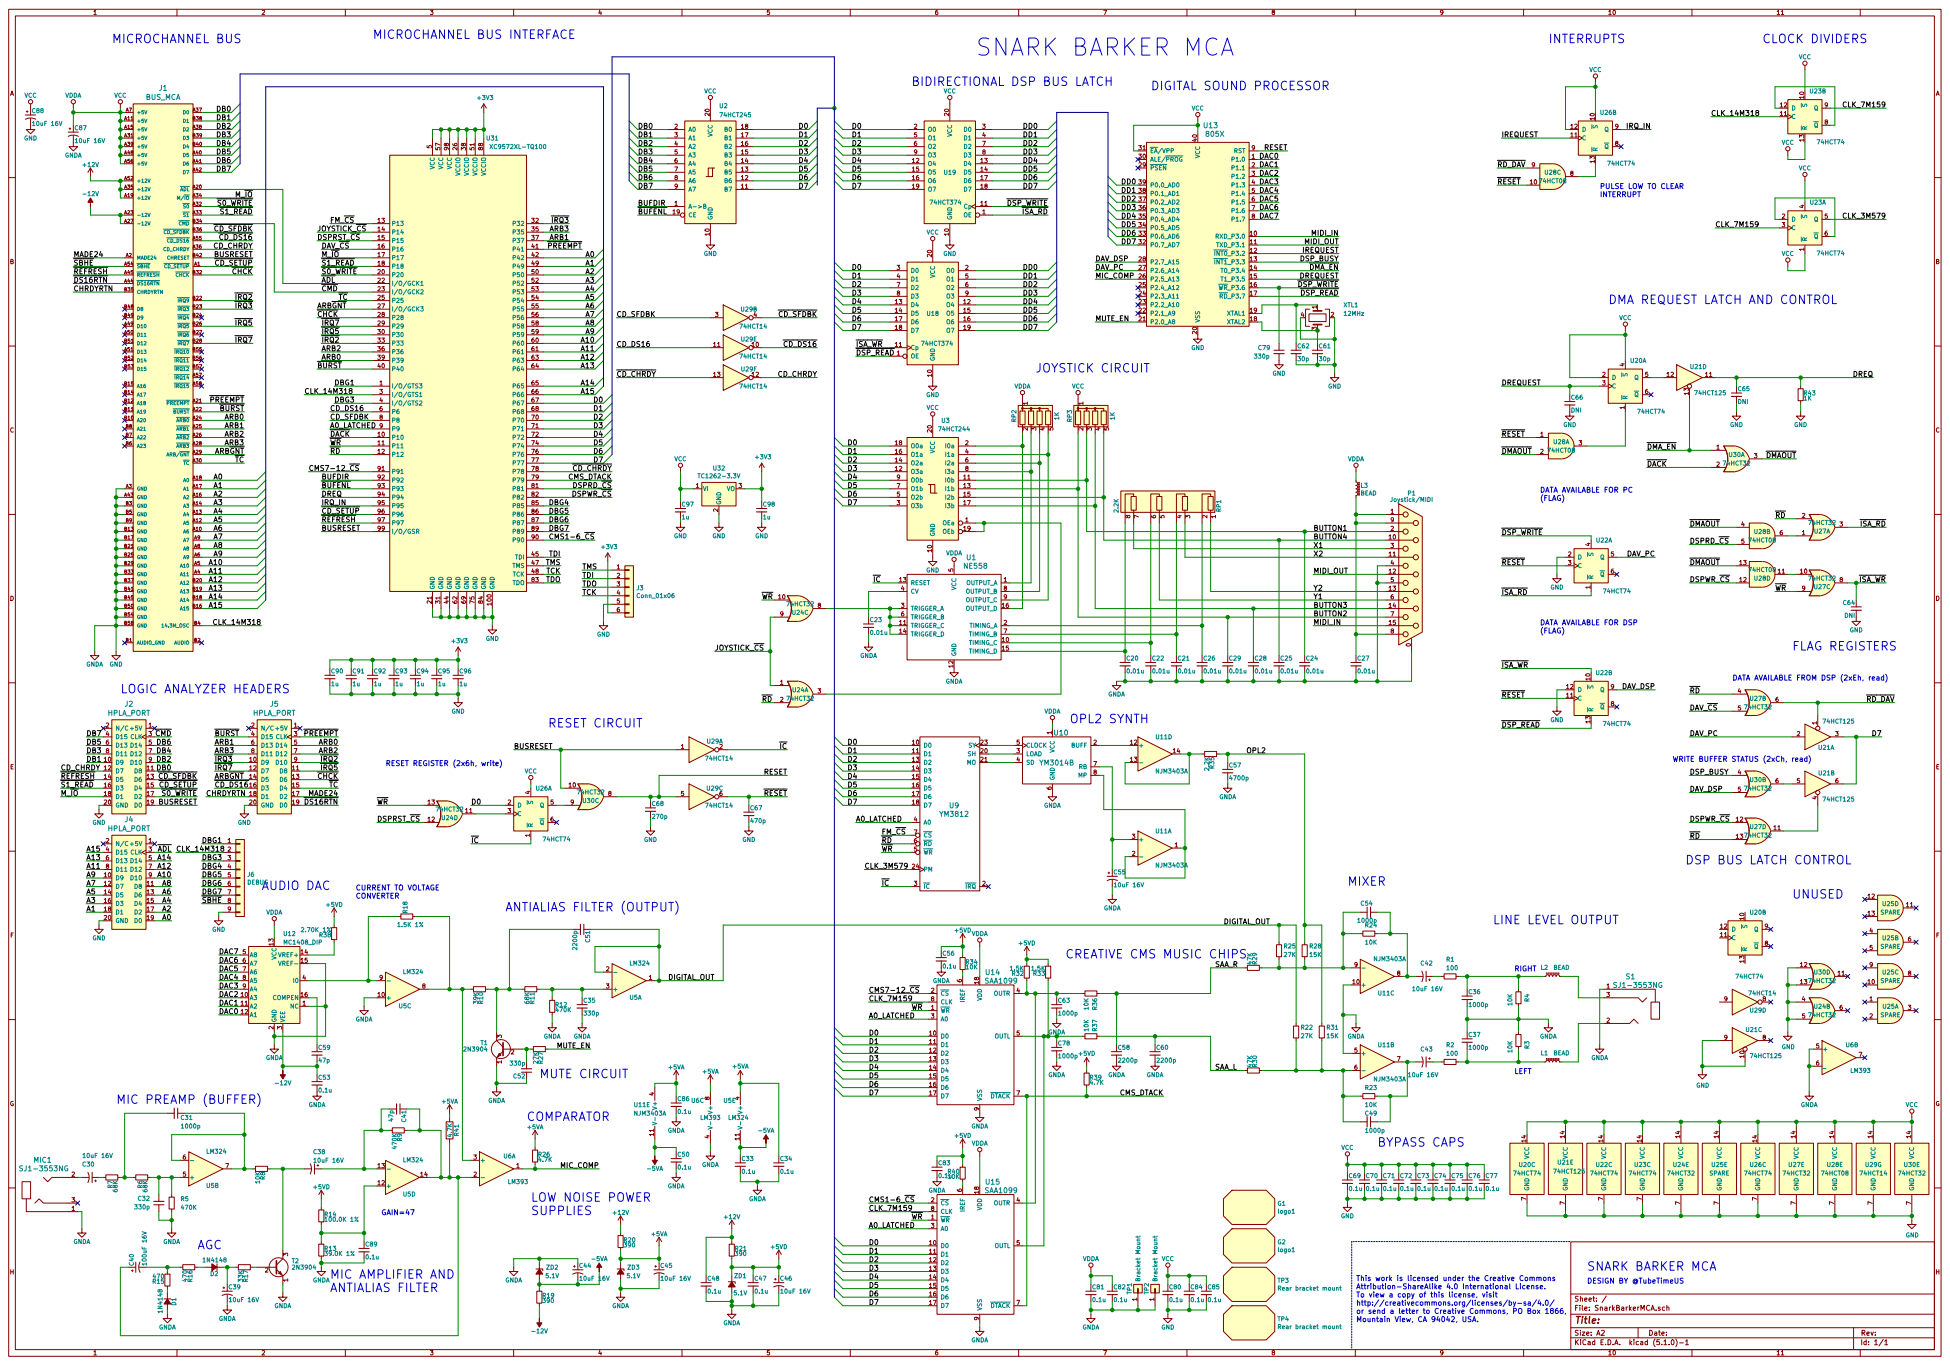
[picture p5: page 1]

5 P50 50 VCCIO 51 P52 52 P53 53 P54 54 P55 55 P56 56 VCC 57 P58 58 P59 59 P6 6 P60 60 P61 61 GND 62 P63 63 P64 64 P65 65 P66 66 P67 67 P68 68 GND 69 P70 70 P71 71 P72 72 P74 74 GND 75 P76 76 P77 77 P78 78 P79 79 P8 8 P81 81 P82 82 TDO 83 GND 84 P85 85 P86 86 P87 87 VCCIO 88 P89 89 P9 9 P90 90 P91 91 P92 92 P93 93 P94 94 P95 95 P96 96 P97 97 VCC 98
JOYSTICK_CS WR

DD0 DD1 DD2 DD3 DD4 DD5 DD6 DD7 RESET REGISTER (2x6h, write)
CHRESET B42 GND B45 GND B5 GND B9

PULSE LOW TO CLEAR

DMA REQUEST LATCH AND CONTROL

DATA AVAILABLE FOR PC
(FLAG)

GND GND GND RESET

DATA AVAILABLE FOR DSP

DATA AVAILABLE FROM DSP (2xEh, read)

WRITE BUFFER STATUS (2xCh, read)
DSP_BUSY

DSP BUS LATCH CONTROL

CREATIVE CMS MUSIC CHIPS

9 U14 SAA1099 WR 1 D0 10 D1 11 D2 12 D3 13 D4 14 D5 15 D6 16 D7 17 VDD 18 CS 2 A0 3 OUTR 4 OUTL 5 IREF

Mountain View, CA 94042, USA. V- 4 V+

logo1 TP3Rear bracket mount TP4Rear bracket mount

Attribution-ShareAlike 4.0 International License.
To view a copy of this license, visit
http://creativecommons.org/licenses/by-sa/4.0/
or send a letter to Creative Commons, PO Box 1866,

Id: 1/1 Title: File: SnarkBarkerMCA.sch Sheet: /

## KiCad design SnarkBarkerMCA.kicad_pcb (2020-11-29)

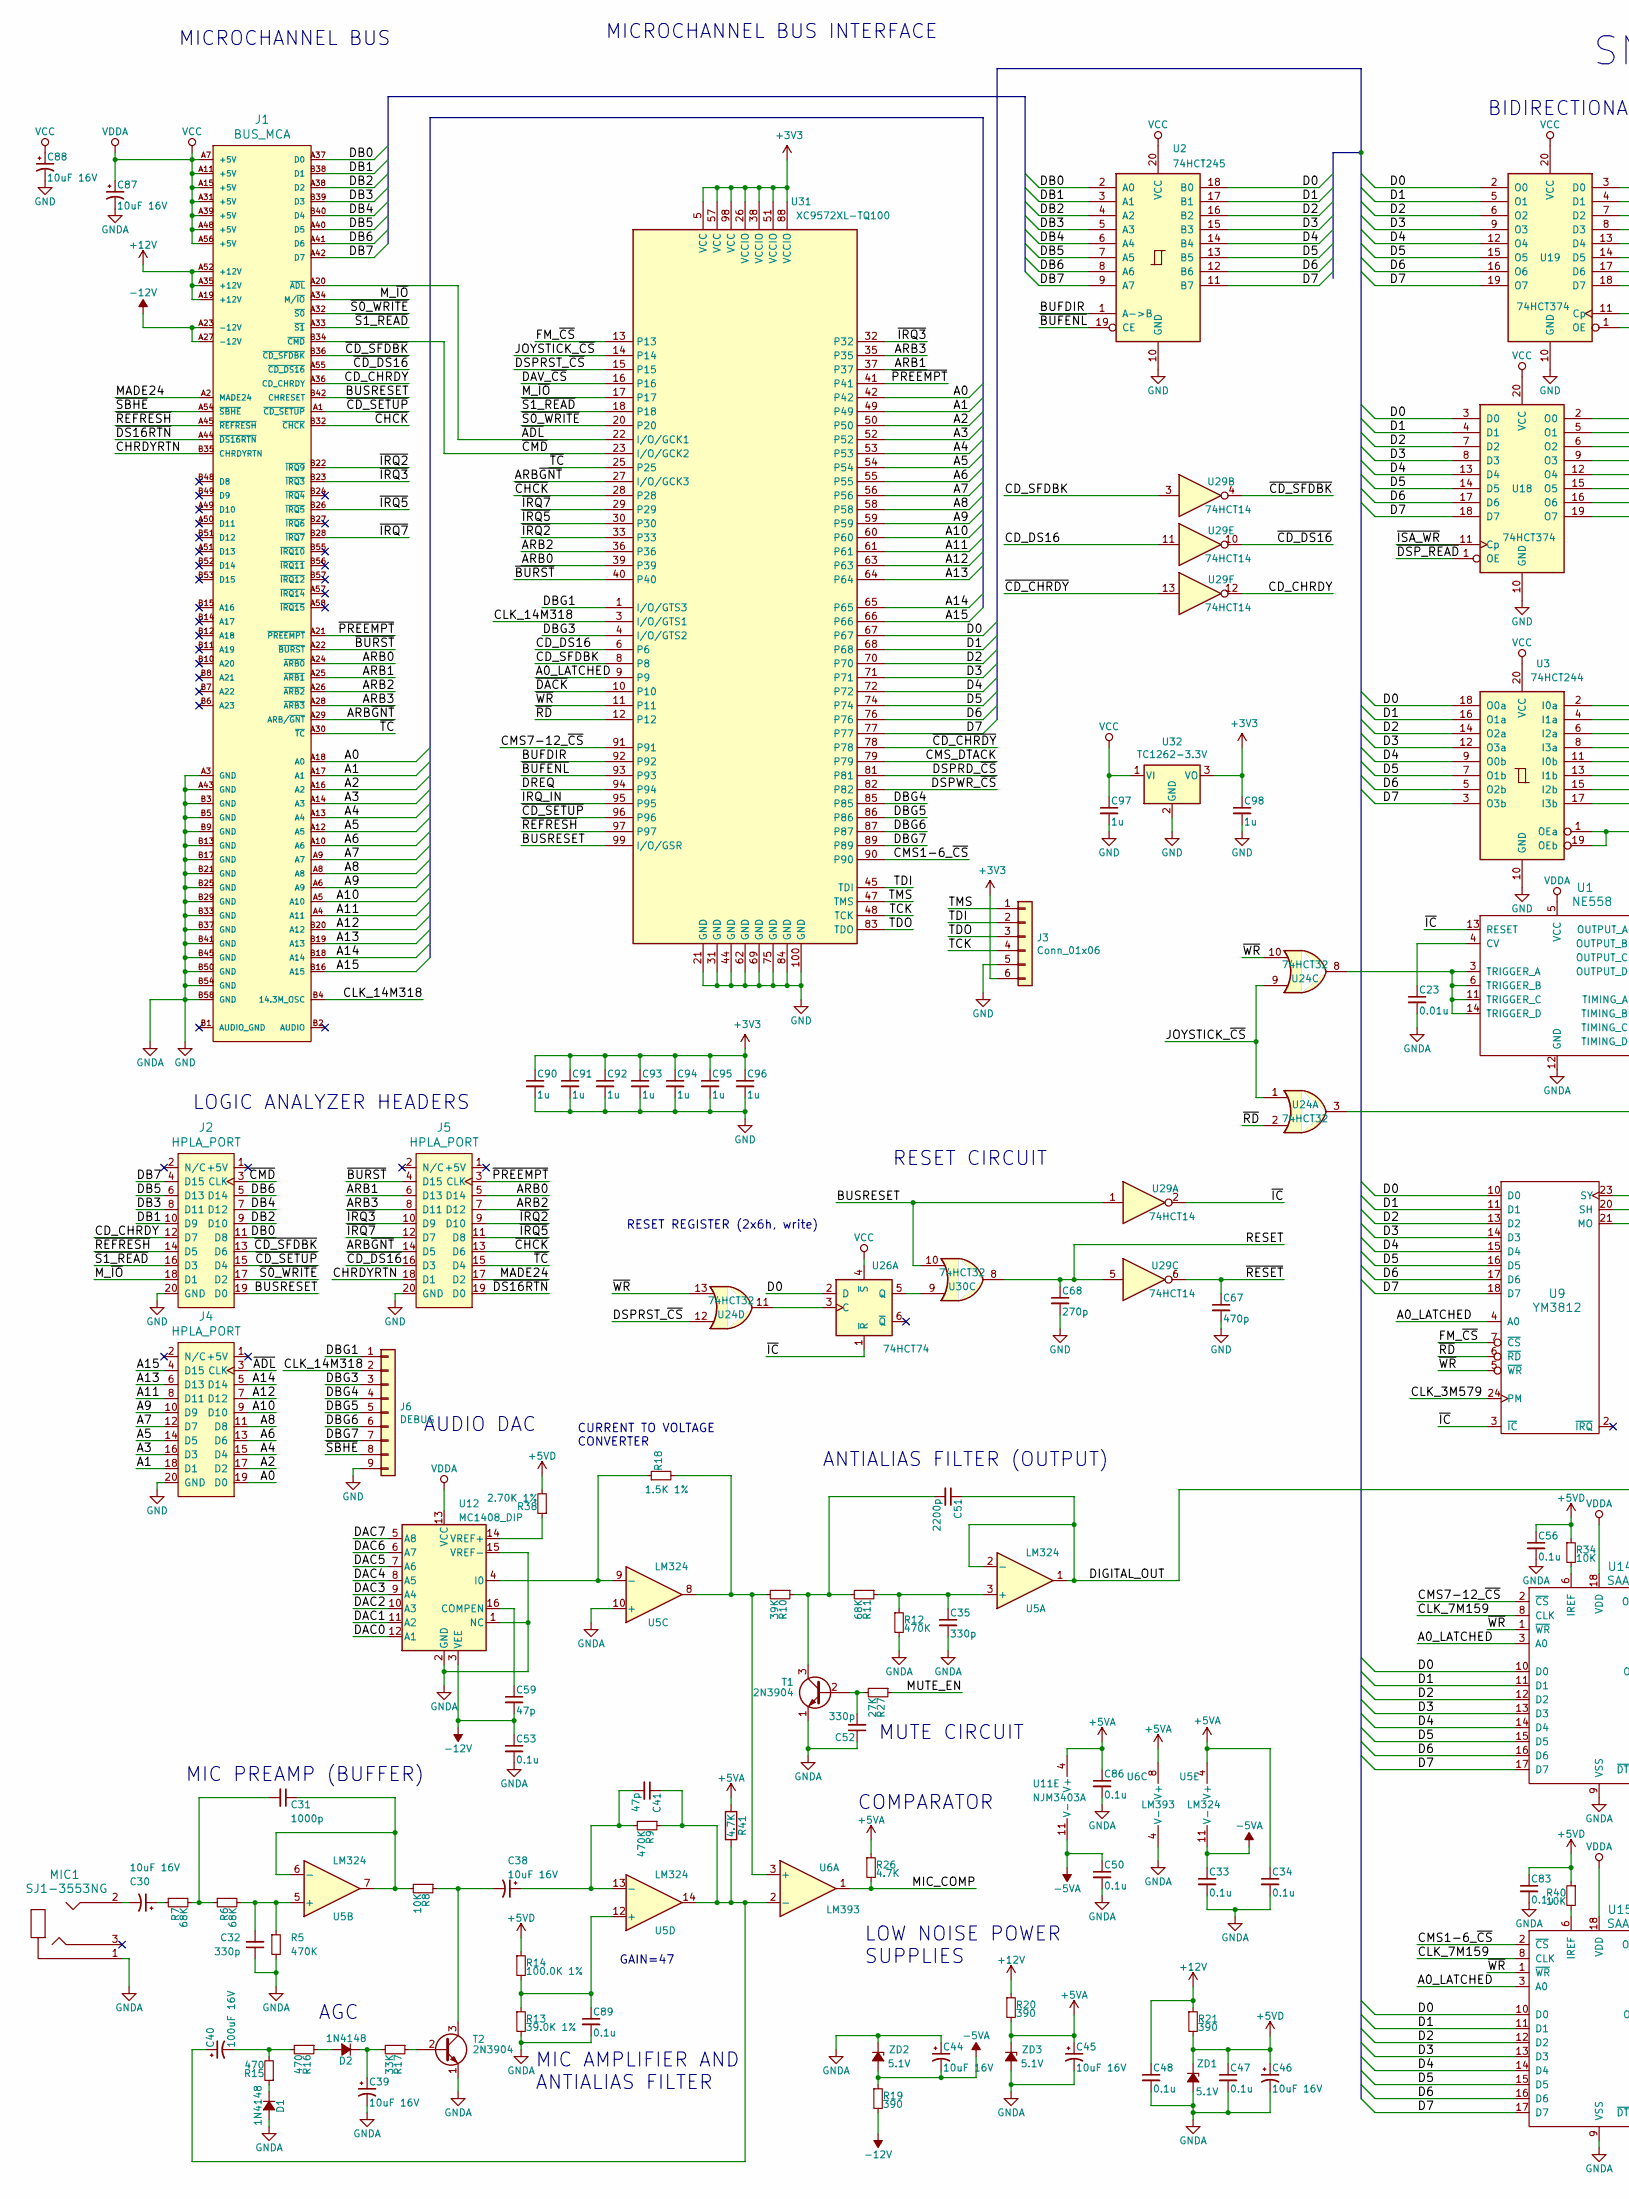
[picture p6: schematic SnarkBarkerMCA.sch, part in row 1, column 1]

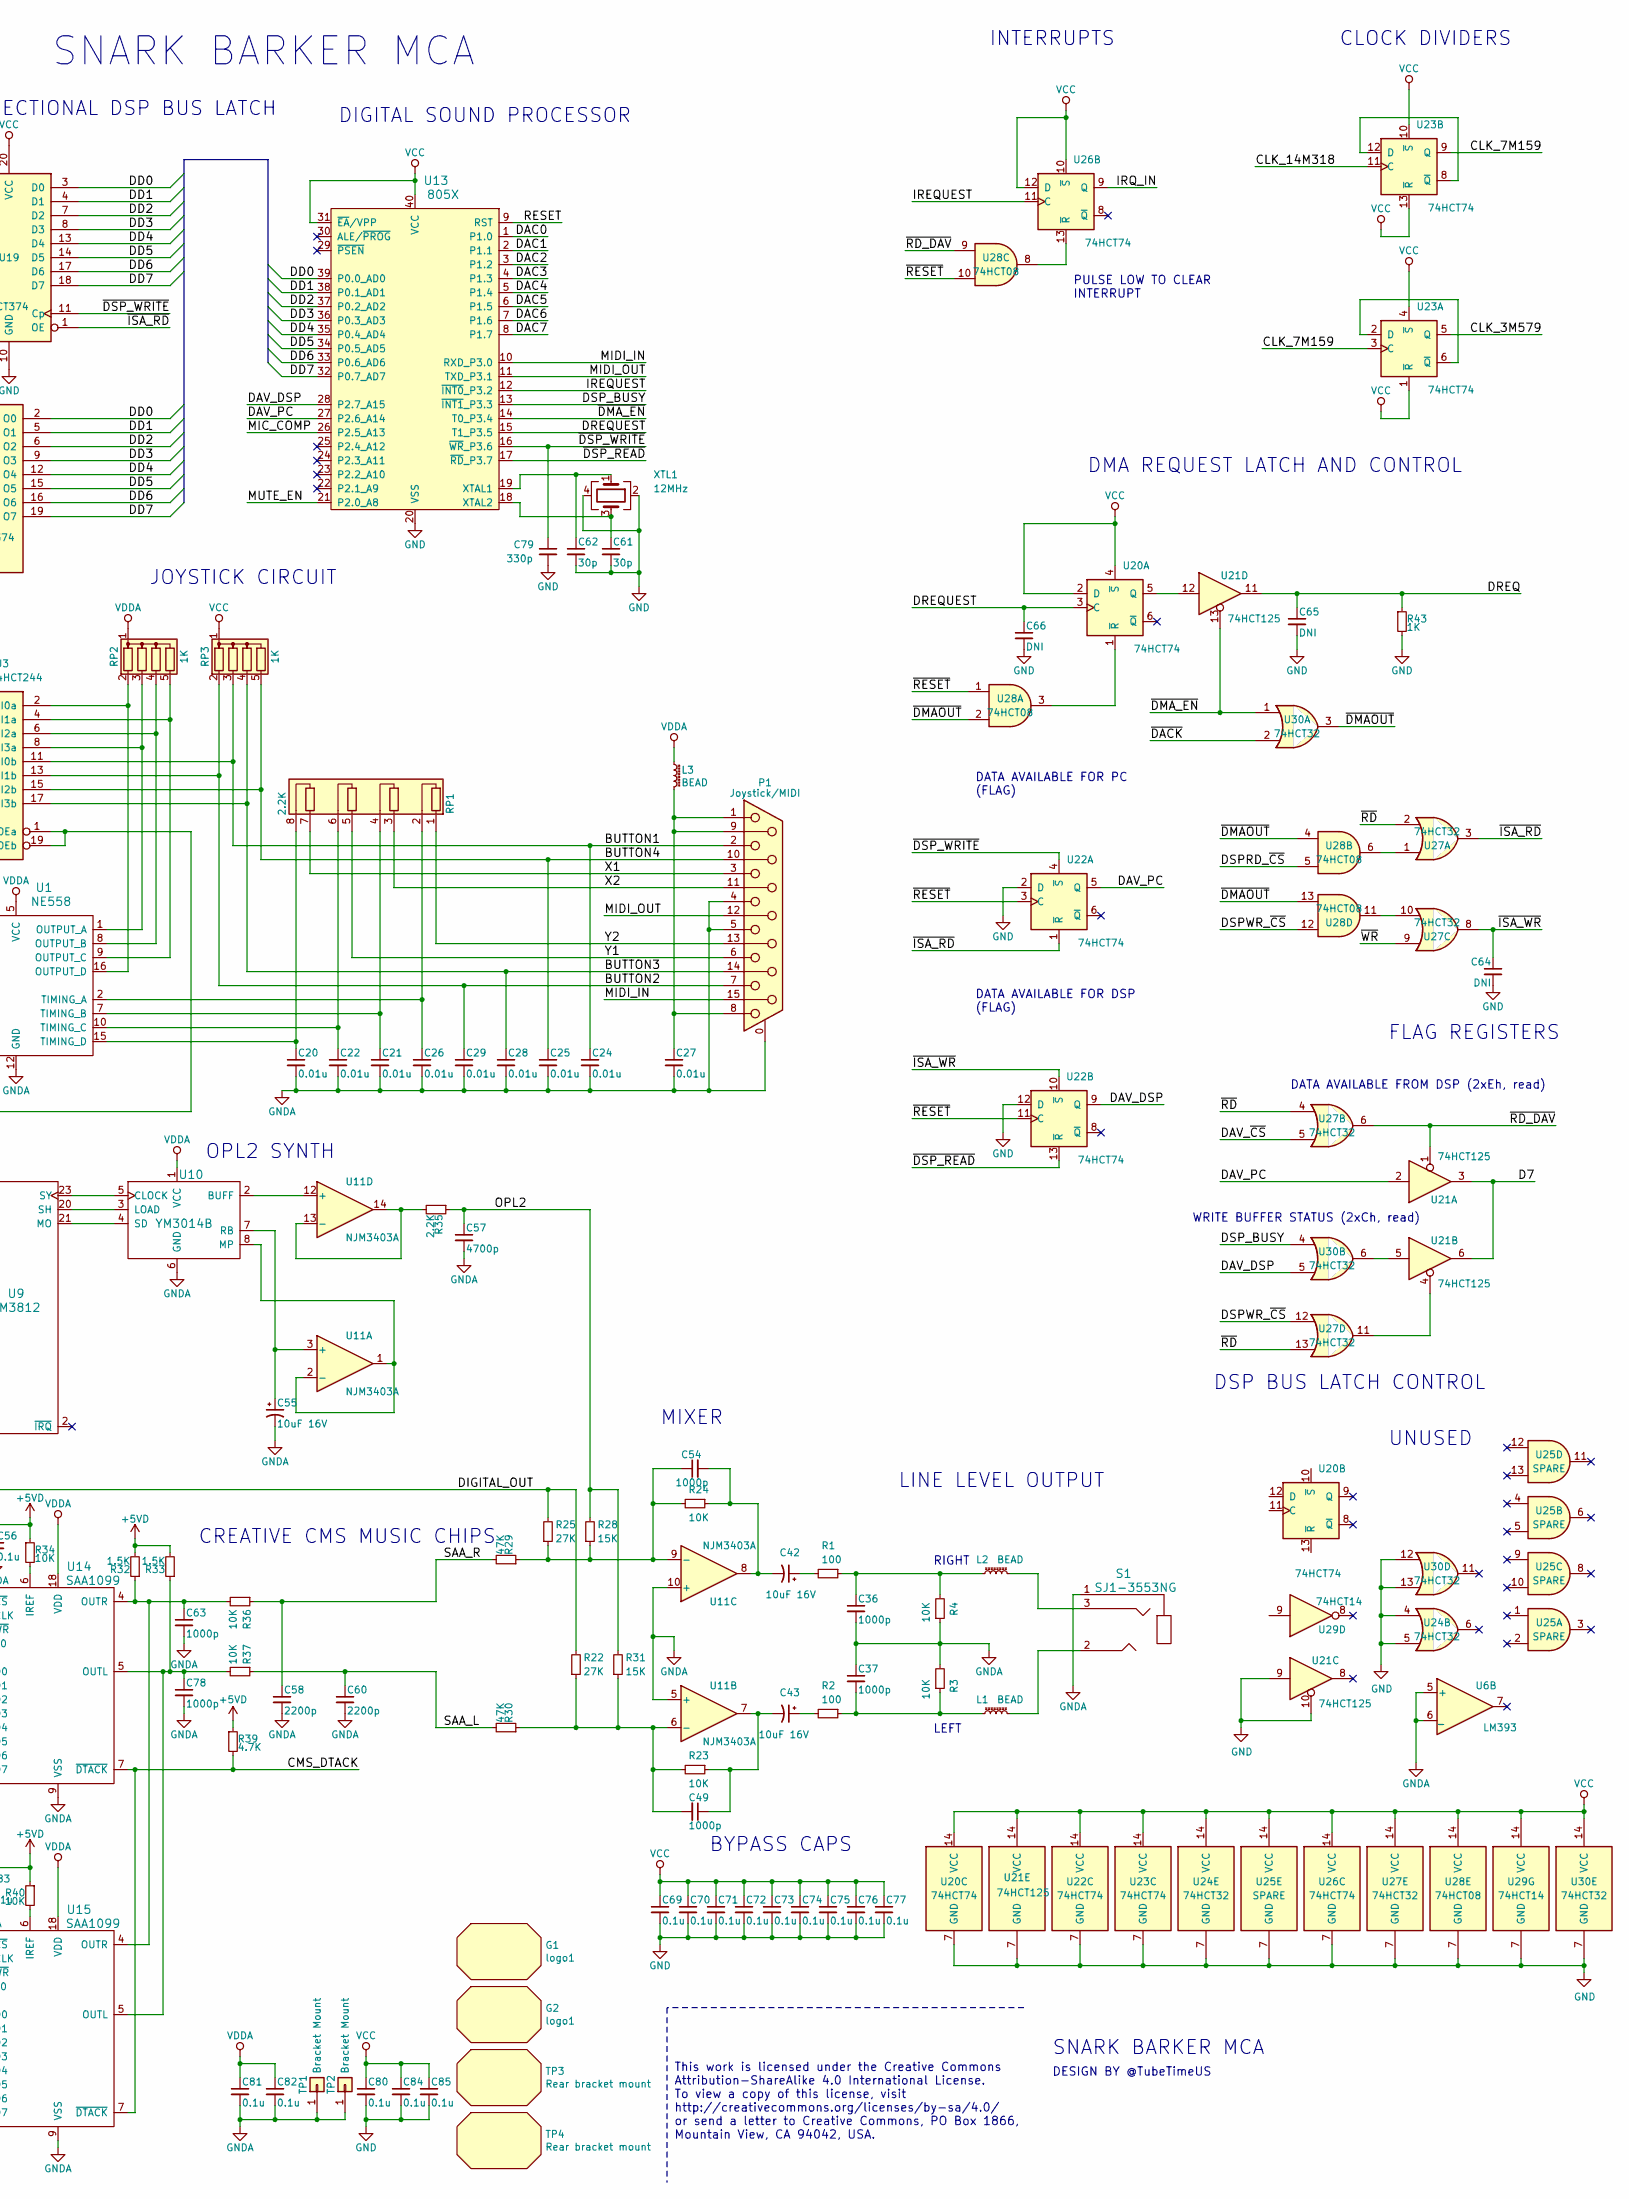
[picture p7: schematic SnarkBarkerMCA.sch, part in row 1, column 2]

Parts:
C20, C21, C22, C23, C24, C25, C26, C27, C28, C29: 0.01u; SB_C_DISC_200; Mouser 810-FG28X7R1H103KNT0
C30, C38, C39, C42, C43, C44, C45, C46, C55, C87, C88: 10uF 16V; SB_C_RADIAL_75_150; Mouser 667-ECA-1CM100I
C31, C36, C37, C49, C54, C63, C78: 1000p; SB_C_DISC_200; Mouser 810-FG28X7R1H102KNT6
C32, C35, C52, C79: 330p; SB_C_DISC_200; Mouser 810-FG28C0G1H331JNT6
C33, C34, C47, C48, C50, C53, C56, C69, C70, C71, C72, C73, C74, C75, C76, C77, C80, C81, C82, C83, C84, C85, C86, C89: 0.1u; SB_C_AXIAL_275; Mouser 581-SA105E104M
C40: 100uF 16V; SB_C_RADIAL_100_320; Mouser 667-ECA-1CM101I
C41, C59: 47p; SB_C_DISC_200; Mouser 810-FG28C0G1H470JNT6
C51, C58, C60: 2200p; SB_C_DISC_200; Mouser 810-FG28X7R1H222KNT6
C57: 4700p; SB_C_DISC_200; Mouser 810-FG28C0G1H472JNT6
C61, C62: 30p; SB_C_DISC_200; Mouser 810-FG28C0G1H270JNT6
C64, C65, C66: DNI; SB_C_DISC_200
C67: 470p; SB_C_DISC_200; Mouser 810-FG28C0G1H471JNT6
C68: 270p; SB_C_DISC_200; Mouser 810-FG28C0G1H271JNT0
C90, C91, C92, C93, C94, C95, C96, C97, C98: 1u; CAPC2012X55; Mouser 187-CL21B105KAFNNNE
D1, D2: 1N4148; SB_D_AXIAL_400; Mouser 512-1N4148
G1, G2: logo1; Snark_BarkerMCA
J1: BUS_MCA
J2, J4, J5: HPLA_PORT; Pin_Header_Straight_2x10_Pitch2.54mm
J3: Conn_01x06; Pin_Header_Straight_1x06_Pitch2.54mm
J6: DEBUG; Pin_Header_Straight_1x09_Pitch2.54mm
L1, L2, L3: BEAD; SB_L_AXIAL_500; Mouser 623-2743004111
MIC1: SJ1-3553NG; SB_SJ1-3553; Mouser 490-SJ1-3553NG
P1: Joystick/MIDI; SB_DB15_152-3415; Mouser 152-3415
R1, R2: 100; SB_R_AXIAL_400; Mouser 603-CFR-25JB-52-100R
R3, R4, R8, R23, R24, R34, R36, R37, R40: 10K; SB_R_AXIAL_400; Mouser 603-CFR-25JB-52-10K
R5, R9, R12: 470K; SB_R_AXIAL_400; Mouser 603-CFR-25JR-52470K
R6, R7, R11: 68K; SB_R_AXIAL_400; Mouser 603-CFR-25JB-52-68K
R10: 39K; SB_R_AXIAL_400; Mouser 603-CFR-25JB-52-39K
R13: 39.0K 1%; SB_R_AXIAL_400; Mouser 603-MFR-25FBF52-39K
R14: 100.0K 1%; SB_R_AXIAL_400; Mouser 603-MFR-25FBF52-100K
R15, R16: 470; SB_R_AXIAL_400; Mouser 603-CFR-25JB-52-470R
R17: 33K; SB_R_AXIAL_400; Mouser 603-CFR-25JB-52-33K
R18: 1.5K 1%; SB_R_AXIAL_400; Mouser 603-MFR-25FBF52-1K5
R19, R20, R21: 390; SB_R_AXIAL_400; Mouser 603-CFR-25JB-52-390R
R22, R25, R27: 27K; SB_R_AXIAL_400; Mouser 603-CFR-25JB-52-27K
R26, R39, R41: 4.7K; SB_R_AXIAL_400; Mouser 603-CFR-25JB-52-4K7
R28, R31: 15K; SB_R_AXIAL_400; Mouser 603-CFR-25JB-52-15K
R29, R30: 47K; SB_R_AXIAL_400; Mouser 603-CFR-25JB-52-47K
R32, R33: 1.5K; SB_R_AXIAL_400; Mouser 603-CFR-25JB-52-1K5
R35: 2.2K; SB_R_AXIAL_400; Mouser 603-CFR-25JB-52-2K2
R38: 2.70K 1%; SB_R_AXIAL_400; Mouser 603-MFR-25FBF52-2K7
R43: 1K; SB_R_AXIAL_400; Mouser 603-CFR-25JR-521K
RP1: 2.2K; SB_RP_4B; Mouser 652-4608X-AP2-222LF
RP2, RP3: 1K; SB_RP_4C; Mouser 652-4605X-AP1-102LF
S1: SJ1-3553NG; SB_SJ1-3553; Mouser 490-SJ1-3553NG
T1, T2: 2N3904; SB_TO92; Mouser 833-2N3904-AP
TP1, TP2: Bracket Mount; MH_125_200
TP3, TP4: Rear bracket mount; MH_125
U1: NE558; SB_DIP16_300
U2: 74HCT245; SB_DIP20_300; Mouser 595-SN74HCT245NE4
U3: 74HCT244; SB_DIP20_300; Mouser 595-SN74HCT244NE4
U5: LM324; SB_DIP14_300; Mouser 926-LM324AN/NOPB
U6: LM393; SB_DIP8_300; Mouser 595-LM393P
U9: YM3812; SB_DIP24_600
U10: YM3014B; SB_DIP8_300
U11: NJM3403A; SB_DIP14_300; Mouser 513-NJM3403AD
U12: MC1408_DIP; SB_DIP16_300; Mouser 926-DAC0808LCN/NOPB
U13: 805X; SB_DIP40_600; Mouser 556-A89S51-24PU
U14, U15: SAA1099; SB_DIP18_300
U18, U19: 74HCT374; SB_DIP20_300; Mouser 595-SN74HCT374N
U20, U22, U23, U26: 74HCT74; SB_DIP14_300; Mouser 595-SN74HCT74NE4
U21: 74HCT125; SB_DIP14_300; Mouser 595-SN74HCT125NE4
U24, U27, U30: 74HCT32; SB_DIP14_300; Mouser 595-SN74HCT32NE4
U25: SPARE; SB_DIP14_300
U28: 74HCT08; SB_DIP14_300; Mouser 595-SN74HCT08NE4
U29: 74HCT14; SB_DIP14_300; Mouser 595-SN74HCT14N
U31: XC9572XL-TQ100; TQFP50P1600X1600X140-100; Mouser 217-9572XL-10TQG100C
U32: TC1262-3.3V; SOT230P700X170-3; Mouser 579-TC1262-3.3VDB
XTL1: 12MHz; SB_XTAL_HC49U_RA; Mouser 815-AB-12-B2
ZD1, ZD2, ZD3: 5.1V; SB_D_AXIAL_400_ALT; Mouser 78-1N5231B-TAP

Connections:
+3V3: C90.1, C91.1, C92.1, C93.1, C94.1, C95.1, C96.1, C98.1, J3.6, U31.5 (VCC), U31.26 (VCCIO), U31.38 (VCCIO), U31.51 (VCCIO), U31.57 (VCC), U31.88 (VCCIO), U31.98 (VCC), U32.3 (VO)
+5VA: C34.1, C45.1, C86.1, R20.2, R26.1, R41.1, U5.4 (V+), U6.8 (V+), U11.4 (V+), ZD3.1 (K)
+5VD: C46.1, C47.1, C56.1, C83.1, R14.1, R21.2, R32.2, R33.2, R34.1, R38.2, R39.1, R40.1, ZD1.1 (K)
+12V: C48.1, J1.A19 (+12V), J1.A35 (+12V), J1.A52 (+12V), R20.1, R21.1
-5VA: C33.1, C44.2, C50.1, R19.1, U5.11 (V-), U11.11 (V-), ZD2.2 (A)
-12V: C53.1, C59.2, J1.A23 (-12V), J1.A27 (-12V), R19.2, U12.3 (VEE)
/A0: J1.A18 (A0), J4.19 (D0), U31.42
/A0_LATCHED: U9.4 (A0), U14.3 (A0), U15.3 (A0), U31.9
/A1: J1.A17 (A1), J4.18 (D1), U31.49
/A2: J1.A16 (A2), J4.17 (D2), U31.50
/A3: J1.A14 (A3), J4.16 (D3), U31.52
/A4: J1.A13 (A4), J4.15 (D4), U31.53
/A5: J1.A12 (A5), J4.14 (D5), U31.54
/A6: J1.A10 (A6), J4.13 (D6), U31.55
/A7: J1.A9 (A7), J4.12 (D7), U31.56
/A8: J1.A8, J4.11 (D8), U31.58
/A9: J1.A6 (A9), J4.10 (D9), U31.59
/A10: J1.A5 (A10), J4.9 (D10), U31.60
/A11: J1.A4 (A11), J4.8 (D11), U31.61
/A12: J1.B20 (A12), J4.7 (D12), U31.63
/A13: J1.B19 (A13), J4.6 (D13), U31.64
/A14: J1.B18 (A14), J4.5 (D14), U31.65
/A15: J1.B16 (A15), J4.4 (D15), U31.66
/ARB0: J1.A24 (~ARB0), J5.5 (D14), U31.39
/ARB1: J1.A25 (~ARB1), J5.6 (D13), U31.37
/ARB2: J1.A26 (~ARB2), J5.7 (D12), U31.36
/ARB3: J1.A28 (~ARB3), J5.8 (D11), U31.35
/ARB~GNT: J1.A29 (ARB/~GNT), J5.14 (D5), U31.27 (I/O/GCK3)
/BUFDIR: U2.1 (A->B), U31.92
/BUSRESET: J1.B42 (CHRESET), J2.19 (D0), U29.1, U30.10, U31.99 (I/O/GSR)
/BUTTON1: C24.1, P1.2, RP3.3 (R2), U3.11 (I0b)
/BUTTON2: C29.1, P1.7, RP3.2 (R1), U3.13 (I1b)
/BUTTON3: C28.1, P1.14, RP3.4 (R3), U3.17 (I3b)
/BUTTON4: C25.1, P1.10, RP3.5 (R4), U3.15 (I2b)
/CD_CHRDY: J1.A36 (CD_CHRDY), J2.12 (D7), U29.12
/CD_DS16: U29.11, U31.6
/CD_SFDBK: U29.3, U31.8
/CHRDYRTN: J1.B35 (CHRDYRTN), J5.18 (D1)
/CLK_3M579: U9.24 (PM), U23.5 (Q)
/CLK_7M159: U14.8 (CLK), U15.8 (CLK), U23.3 (C), U23.9 (Q)
/CLK_14M318: J1.B4 (14.3M_OSC), J6.2, U23.11 (C), U31.3 (I/O/GTS1)
/CMS1-6_~CS: U15.2 (~CS), U31.90
/CMS7-12_~CS: U14.2 (~CS), U31.91
/CMS_DTACK: R39.2, U14.7 (~DTACK), U15.7 (~DTACK), U31.79
/D0: U2.18 (B0), U3.18 (O0a), U9.10 (D0), U14.10 (D0), U15.10 (D0), U18.3 (D0), U19.2 (O0), U26.2 (D), U31.67
/D1: U2.17 (B1), U3.16 (O1a), U9.11 (D1), U14.11 (D1), U15.11 (D1), U18.4 (D1), U19.5 (O1), U31.68
/D2: U2.16 (B2), U3.14 (O2a), U9.13 (D2), U14.12 (D2), U15.12 (D2), U18.7 (D2), U19.6 (O2), U31.70
/D3: U2.15 (B3), U3.12 (O3a), U9.14 (D3), U14.13 (D3), U15.13 (D3), U18.8 (D3), U19.9 (O3), U31.71
/D4: U2.14 (B4), U3.9 (O0b), U9.15 (D4), U14.14 (D4), U15.14 (D4), U18.13 (D4), U19.12 (O4), U31.72
/D5: U2.13 (B5), U3.7 (O1b), U9.16 (D5), U14.15 (D5), U15.15 (D5), U18.14 (D5), U19.15 (O5), U31.74
/D6: U2.12 (B6), U3.5 (O2b), U9.17 (D6), U14.16 (D6), U15.16 (D6), U18.17 (D6), U19.16 (O6), U31.76
/D7: U2.11 (B7), U3.3 (O3b), U9.18 (D7), U14.17 (D7), U15.17 (D7), U18.18 (D7), U19.19 (O7), U21.3, U21.6, U31.77
/DAC0: U12.12 (A1), U13.1 (P1.0)
/DAC1: U12.11 (A2), U13.2 (P1.1)
/DAC2: U12.10 (A3), U13.3 (P1.2)
/DAC3: U12.9 (A4), U13.4 (P1.3)
/DAC4: U12.8 (A5), U13.5 (P1.4)
/DAC5: U12.7 (A6), U13.6 (P1.5)
/DAC6: U12.6 (A7), U13.7 (P1.6)
/DAC7: U12.5 (A8), U13.8 (P1.7)
/DAV_DSP: U13.28 (P2.7_A15), U22.9 (Q), U30.5
/DAV_PC: U13.27 (P2.6_A14), U21.2, U22.5 (Q)
/DAV_~CS: U27.5, U31.16
/DB0: J1.A37 (D0), J2.11 (D8), U2.2 (A0)
/DB1: J1.B38 (D1), J2.10 (D9), U2.3 (A1)
/DB2: J1.A38 (D2), J2.9 (D10), U2.4 (A2)
/DB3: J1.B39 (D3), J2.8 (D11), U2.5 (A3)
/DB4: J1.B40 (D4), J2.7 (D12), U2.6 (A4)
/DB5: J1.A40 (D5), J2.6 (D13), U2.7 (A5)
/DB6: J1.A41 (D6), J2.5 (D14), U2.8 (A6)
/DB7: J1.A42 (D7), J2.4 (D15), U2.9 (A7)
/DBG1: J6.1, U31.1 (I/O/GTS3)
/DBG3: J6.3, U31.4 (I/O/GTS2)
/DBG4: J6.4, U31.85
/DBG5: J6.5, U31.86
/DBG6: J6.6, U31.87
/DBG7: J6.7, U31.89
/DD0: U13.39 (P0.0_AD0), U18.2 (O0), U19.3 (D0)
/DD1: U13.38 (P0.1_AD1), U18.5 (O1), U19.4 (D1)
/DD2: U13.37 (P0.2_AD2), U18.6 (O2), U19.7 (D2)
/DD3: U13.36 (P0.3_AD3), U18.9 (O3), U19.8 (D3)
/DD4: U13.35 (P0.4_AD4), U18.12 (O4), U19.13 (D4)
/DD5: U13.34 (P0.5_AD5), U18.15 (O5), U19.14 (D5)
/DD6: U13.33 (P0.6_AD6), U18.16 (O6), U19.17 (D6)
/DD7: U13.32 (P0.7_AD7), U18.19 (O7), U19.18 (D7)
/DIGITAL_OUT: C51.1, R22.2, R25.2, U5.1, U5.2 (-)
/DREQ: C65.1, R43.1, U21.11, U31.94
/DREQUEST: C66.1, U13.15 (T1_P3.5), U20.3 (C)
/DSPRD_~CS: U28.5, U31.81
/DSPRST_~CS: U24.12, U31.15
/DSPWR_~CS: U27.12, U28.12, U31.82
/DSP_BUSY: U13.13 (~INT1~_P3.3), U30.4
/FM_~CS: U9.7 (~CS), U31.13
/IREQUEST: U13.12 (~INT0~_P3.2), U26.11 (C)
/IRQ_IN: U26.9 (Q), U31.95
/JOYSTICK_~CS: U24.1, U24.9, U31.14
/MADE24: J1.A2 (MADE24), J5.17 (D2)
/MIC_COMP: R26.2, U6.1, U13.26 (P2.5_A13)
/MIDI_IN: P1.15, U13.10 (RXD_P3.0)
/MIDI_OUT: P1.12, U13.11 (TXD_P3.1)
/MUTE_EN: R27.1, U13.21 (P2.0_A8)
/M_~IO: J1.A34 (M/~IO), J2.18 (D1), U31.17
/OPL2: C57.1, R28.2, R31.2, R35.1
/RESET: C68.1, U13.9 (RST), U29.5, U30.8
/SAA_L: C60.1, R30.2, R37.1
/SAA_R: C58.1, R29.2, R36.1
/TCK: J3.4, U31.48 (TCK)
/TDI: J3.2, U31.45 (TDI)
/TDO: J3.3, U31.83 (TDO)
/TMS: J3.1, U31.47 (TMS)
/X1: P1.3, RP1.7 (R4.1)
/X2: P1.11 (P111), RP1.3 (R2.1)
/Y1: P1.6, RP1.5 (R3.1)
/Y2: P1.13, RP1.1 (R1.1)
/~ADL: J1.A20 (~ADL), J4.3 (CLK), U31.22 (I/O/GCK1)
/~BUFENL: U2.19 (CE), U31.93
/~BURST: J1.A22 (~BURST), J5.4 (D15), U31.40
/~CD_CHRDY: U29.13, U31.78
/~CD_DS16: J1.A55 (~CD_DS16), J5.16 (D3), U29.10
/~CD_SETUP: J1.A1 (~CD_SETUP), J2.15 (D4), U31.96
/~CD_SFDBK: J1.B36 (~CD_SFDBK), J2.13 (D6), U29.4
/~CHCK: J1.B32 (~CHCK), J5.13 (D6), U31.28
/~CMD: J1.B34 (~CMD), J2.3 (CLK), U31.23 (I/O/GCK2)
/~DACK: U30.2, U31.10
/~DMAOUT: U28.2, U28.4, U28.13, U30.3
/~DMA_EN: U13.14 (T0_P3.4), U21.13, U30.1
/~DS16RTN: J1.A44 (~DS16RTN), J5.19 (D0)
/~DSP_READ: U13.17 (~RD~_P3.7), U18.1 (OE), U22.13 (~R)
/~DSP_WRITE: C79.1, U13.16 (~WR~_P3.6), U19.11 (Cp), U22.4 (~S)
/~IC: U1.13 (RESET), U9.3 (~IC), U26.1 (~R), U29.2
/~IRQ2: J1.B22 (~IRQ9), J5.9 (D10), U31.33
/~IRQ3: J1.B23 (~IRQ3), J5.10 (D9), U31.32
/~IRQ5: J1.B26 (~IRQ5), J5.11 (D8), U31.30
/~IRQ7: J1.B28 (~IRQ7), J5.12 (D7), U31.29
/~ISA_RD: U19.1 (OE), U22.1 (~R), U27.3
/~ISA_WR: C64.1, U18.11 (Cp), U22.10 (~S), U27.8
/~PREEMPT: J1.A21 (~PREEMPT), J5.3 (CLK), U31.41
/~RD: U9.6 (~RD), U24.2, U27.2, U27.4, U27.13, U31.12
/~RD_DAV: U21.1, U27.6, U28.9
/~REFRESH: J1.A45 (~REFRESH), J2.14 (D5), U31.97
/~RESET: C67.1, U22.3 (C), U22.11 (C), U28.1, U28.10, U29.6
/~S0_WRITE: J1.A32 (~S0), J2.17 (D2), U31.20
/~S1_READ: J1.A33 (~S1), J2.16 (D3), U31.18
/~SBHE: J1.A54 (~SBHE), J6.8
/~TC: J1.A30 (~TC), J5.15 (D4), U31.25
/~WR: U9.5 (~WR), U14.1 (~WR), U15.1 (~WR), U24.10, U24.13, U27.9, U31.11
GND: C20.2, C21.2, C22.2, C23.2, C24.2, C25.2, C26.2, C27.2, C28.2, C29.2, C32.1, C33.2, C34.2, C35.2, C36.2, C37.1, C39.2, C44.1, C45.2, C46.2, C47.2, C48.2, C50.2, C52.1, C53.2, C55.2, C56.2, C57.2, C58.2, C60.2, C61.2, C62.2, C63.2, C64.2, C65.2, C66.2, C67.2, C68.2, C69.2, C70.2, C71.2, C72.2, C73.2, C74.2, C75.2, C76.2, C77.2, C78.2, C79.2, C80.2, C81.2, C82.2, C83.2, C84.2, C85.2, C86.2, C87.2, C88.2, C89.2, C90.2, C91.2, C92.2, C93.2, C94.2, C95.2, C96.2, C97.2, C98.2, D1.2 (A), J1.A3 (GND), J1.A43 (GND), J1.B3 (GND), J1.B5 (GND), J1.B9 (GND), J1.B13 (GND), J1.B17 (GND), J1.B21 (GND), J1.B25 (GND), J1.B29 (GND), J1.B33 (GND), J1.B37 (GND), J1.B41 (GND), J1.B45 (GND), J1.B50 (GND), J1.B54 (GND), J1.B58 (GND), J2.20 (GND), J3.5, J4.20 (GND), J5.20 (GND), J6.9, MIC1.1, P1.0 (PAD), P1.4, P1.5, R3.2, R4.1, R5.2, R12.2, R13.2, R43.2, S1.1, T1.1 (E), T2.1 (E), TP1.1, TP2.1, U1.12 (GND), U2.10 (GND), U3.10 (GND), U5.10 (+), U6.4 (V-), U6.5 (+), U6.6 (_), U9.12 (GND), U10.6 (GND), U11.5 (+), U11.10 (+), U12.1 (NC), U12.2 (GND), U12.15 (VREF-), U13.20 (VSS), U14.9 (VSS), U15.9 (VSS), U18.10 (GND), U19.10 (GND), U20.7 (GND), U21.7 (GND), U21.9, U21.10, U22.2 (D), U22.7 (GND), U22.12 (D), U23.7 (GND), U24.4, U24.5, U24.7 (GND), U25.7 (GND), U26.7 (GND), U27.7 (GND), U28.7 (GND), U29.7 (GND), U30.7 (GND), U30.12, U30.13, U31.21 (GND), U31.31 (GND), U31.44 (GND), U31.62 (GND), U31.69 (GND), U31.75 (GND), U31.84 (GND), U31.100 (GND), U32.2 (GND), XTL1.2, XTL1.4, ZD1.2 (A), ZD2.1 (K), ZD3.2 (A)
unnamed: C20.1, RP1.8 (R4.2), U1.15 (TIMING_D)
unnamed: C21.1, RP1.4 (R2.2), U1.7 (TIMING_B)
unnamed: C22.1, RP1.6 (R3.2), U1.10 (TIMING_C)
unnamed: C23.1, U1.4 (CV)
unnamed: C26.1, RP1.2 (R1.2), U1.2 (TIMING_A)
unnamed: C27.1, L3.2, P1.1, P1.8, P1.9
unnamed: C30.1, R7.1
unnamed: C30.2, MIC1.2
unnamed: C31.1, R8.2, U5.6 (-), U5.7
unnamed: C31.2, R6.1, R7.2
unnamed: C32.2, R5.1, R6.2, U5.5 (+)
unnamed: C35.1, R11.1, R12.1, U5.3 (+)
unnamed: C36.1, L2.1, R1.1, R4.2
unnamed: C37.2, L1.1, R2.1, R3.1
unnamed: C38.1, C41.2, R9.2, U5.13 (-)
unnamed: C38.2, R8.1, T2.3 (C)
unnamed: C39.1, D2.1 (K), R17.2
unnamed: C40.1, C41.1, R9.1, R41.2, U5.14, U6.2 (-)
unnamed: C40.2, R15.2, R16.2
unnamed: C42.1, R1.2
unnamed: C42.2, C54.2, R24.1, U11.8
unnamed: C43.1, R2.2
unnamed: C43.2, C49.1, R23.1, U11.7
unnamed: C49.2, R22.1, R23.2, R30.1, R31.1, U11.6 (-)
unnamed: C51.2, R10.1, R11.2, T1.3 (C)
unnamed: C52.2, R27.2, T1.2 (B)
unnamed: C54.1, R24.2, R25.1, R28.1, R29.1, U11.9 (-)
unnamed: C55.1, U10.7 (RB), U11.3 (+)
unnamed: C59.1, U12.16 (COMPEN)
unnamed: C61.1, U13.18 (XTAL2), XTL1.3
unnamed: C62.1, U13.19 (XTAL1), XTL1.1
unnamed: C63.1, R32.1, R36.2, U14.4 (OUTR), U15.4 (OUTR)
unnamed: C78.1, R33.1, R37.2, U14.5 (OUTL), U15.5 (OUTL)
unnamed: C89.1, R13.1, R14.2, U5.12 (+)
unnamed: D1.1 (K), R15.1
unnamed: D2.2 (A), R16.1
unnamed: L1.2, S1.2
unnamed: L2.2, S1.3
unnamed: R10.2, R18.2, U5.8, U6.3 (+)
unnamed: R17.1, T2.2 (B)
unnamed: R18.1, U5.9 (-), U12.4 (I0)
unnamed: R34.2, U14.6 (IREF)
unnamed: R35.2, U11.13 (-), U11.14
unnamed: R38.1, U12.14 (VREF+)
unnamed: R40.2, U15.6 (IREF)
unnamed: RP2.2 (R1), U1.16 (OUTPUT_D), U3.2 (I0a)
unnamed: RP2.3 (R2), U1.1 (OUTPUT_A), U3.8 (I3a)
unnamed: RP2.4 (R3), U1.8 (OUTPUT_B), U3.6 (I2a)
unnamed: RP2.5 (R4), U1.9 (OUTPUT_C), U3.4 (I1a)
unnamed: U1.3 (TRIGGER_A), U1.6 (TRIGGER_B), U1.11 (TRIGGER_C), U1.14 (TRIGGER_D), U24.8
unnamed: U10.2 (BUFF), U11.12 (+)
unnamed: U9.20 (SH), U10.3 (LOAD)
unnamed: U9.21 (MO), U10.4 (SD)
unnamed: U9.23 (SY), U10.5 (CLOCK)
unnamed: U10.8 (MP), U11.1, U11.2 (-)
unnamed: U20.1 (~R), U28.3
unnamed: U20.5 (Q), U21.12
unnamed: U21.4, U27.11
unnamed: U21.5, U30.6
unnamed: U23.2 (D), U23.6 (~Q)
unnamed: U23.8 (~Q), U23.12 (D)
unnamed: U3.1 (OEa), U3.19 (OEb), U24.3
unnamed: U24.11, U26.3 (C)
unnamed: U26.5 (Q), U30.9
unnamed: U26.13 (~R), U28.8
unnamed: U27.1, U28.6
unnamed: U27.10, U28.11
VCC: C69.1, C70.1, C71.1, C72.1, C73.1, C74.1, C75.1, C76.1, C77.1, C80.1, C81.1, C82.1, C84.1, C85.1, C87.1, C88.1, C97.1, J1.A7 (+5V), J1.A11 (+5V), J1.A15 (+5V), J1.A31 (+5V), J1.A39 (+5V), J1.A48 (+5V), J1.A56 (+5V), L3.1, RP2.1 (common), RP3.1 (common), U1.5 (VCC), U2.20 (VCC), U3.20 (VCC), U9.1 (VCC), U10.1 (VCC), U12.13 (VCC), U13.31 (~EA~/VPP), U13.40 (VCC), U14.18 (VDD), U15.18 (VDD), U18.20 (VCC), U19.20 (VCC), U20.2 (D), U20.4 (~S), U20.14 (VCC), U21.14 (VCC), U22.14 (VCC), U23.1 (~R), U23.4 (~S), U23.10 (~S), U23.13 (~R), U23.14 (VCC), U24.14 (VCC), U25.14 (VCC), U26.4 (~S), U26.10 (~S), U26.12 (D), U26.14 (VCC), U27.14 (VCC), U28.14 (VCC), U29.14 (VCC), U30.14 (VCC), U32.1 (VI)

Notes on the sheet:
AGC
MIC PREAMP (BUFFER)
MIC AMPLIFIER AND ANTIALIAS FILTER
GAIN=47
CURRENT TO VOLTAGE CONVERTER
AUDIO DAC
MUTE CIRCUIT
ANTIALIAS FILTER (OUTPUT)
COMPARATOR
MIXER
LINE LEVEL OUTPUT
LEFT
RIGHT
LOW NOISE POWER SUPPLIES
OPL2 SYNTH
CREATIVE CMS MUSIC CHIPS
JOYSTICK CIRCUIT
CLOCK DIVIDERS
PULSE LOW TO CLEAR INTERRUPT
FLAG REGISTERS
INTERRUPTS
DMA REQUEST LATCH AND CONTROL
MICROCHANNEL BUS INTERFACE
RESET CIRCUIT
DATA AVAILABLE FOR PC (FLAG)
DATA AVAILABLE FOR DSP (FLAG)
DATA AVAILABLE FROM DSP (2xEh, read)
WRITE BUFFER STATUS (2xCh, read)
RESET REGISTER (2x6h, write)
MICROCHANNEL BUS
DIGITAL SOUND PROCESSOR
BIDIRECTIONAL DSP BUS LATCH
DSP BUS LATCH CONTROL
UNUSED
SNARK BARKER MCA
DESIGN BY @TubeTimeUS
This work is licensed under the Creative Commons Attribution-ShareAlike 4.0 International License. To view a copy of this license, visit http://creativecommons.org/licenses/by-sa/4.0/ or send a letter to Creative Commons, PO Box 1866, Mountain View, CA 94042, USA.
BYPASS CAPS
LOGIC ANALYZER HEADERS

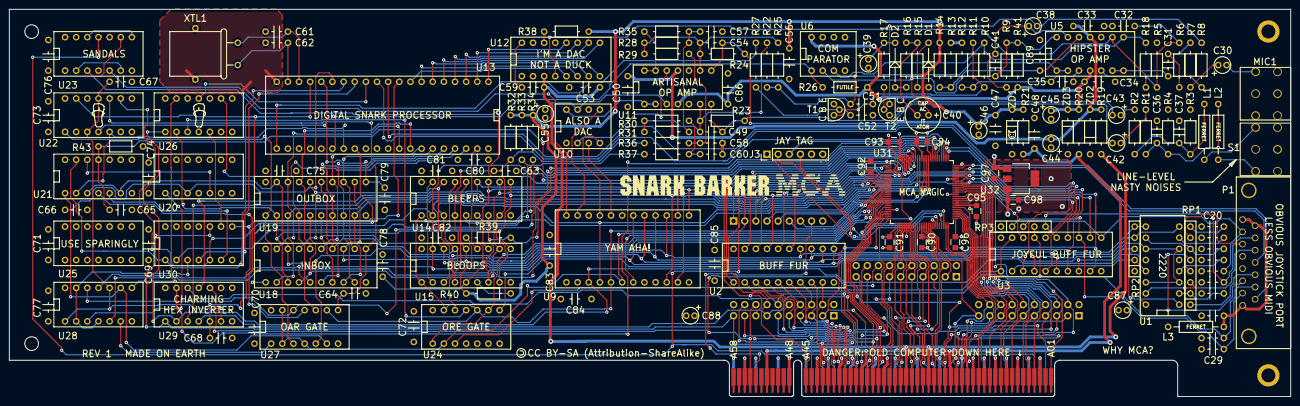
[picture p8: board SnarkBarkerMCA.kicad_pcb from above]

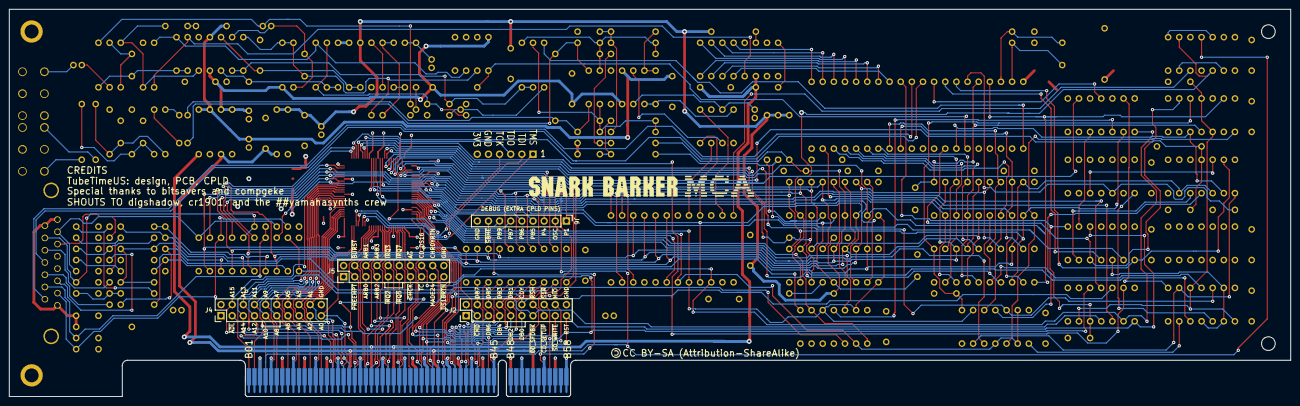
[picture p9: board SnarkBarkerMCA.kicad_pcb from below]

Board: 4 copper layers, 292.1 x 88.3 mm, 177 parts (5 on the bottom side), 215 nets.

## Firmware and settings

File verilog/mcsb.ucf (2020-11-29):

#
# SB MCA CPLD Version - Constraints (pin mapping)
# Copyright (c) 2020 Eric Schlaepfer
# This work is licensed under the Creative Commons Attribution-ShareAlike 4.0
# International License. To view a copy of this license, visit
# http://creativecommons.org/licenses/by-sa/4.0/ or send a letter to Creative
# Commons, PO Box 1866, Mountain View, CA 94042, USA.
#

# Pin map
NET "adl_l" loc="P22";
NET "adl_l" BUFG=CLK;
NET "cmd" loc="P23";
NET "cmd" BUFG=CLK;

NET "arb_grant_l" loc="P27";
NET "arb_grant_l" BUFG=CLK;

NET "cden" loc="P1"; # Card enable signal for debugging (DBG1)
NET "clk14" loc="P3"; # 14.318MHz clock

NET "cd_setup_l" loc="P96";
NET "refresh" loc="P97";
NET "chck_l" loc="P28";
NET "cd_sfdbk" loc="P8";
NET "cd_ds16" loc="P6";
NET "cd_chrdy_l" loc="P78";

NET "m_io" loc="P17";
NET "s0_w_l" loc="P20";
NET "s1_r_l" loc="P18";
NET "a(0)" loc="P42";
NET "a(1)" loc="P49";
NET "a(2)" loc="P50";
NET "a(3)" loc="P52";
NET "a(4)" loc="P53";
NET "a(5)" loc="P54";
NET "a(6)" loc="P55";
NET "a(7)" loc="P56";
NET "a(8)" loc="P58";
NET "a(9)" loc="P59";
NET "a(10)" loc="P60";
NET "a(11)" loc="P61";
NET "a(12)" loc="P63";
NET "a(13)" loc="P64";
NET "a(14)" loc="P65";
NET "a(15)" loc="P66";

NET "d(0)" loc="P67";
NET "d(1)" loc="P68";
NET "d(2)" loc="P70";
NET "d(3)" loc="P71";
NET "d(4)" loc="P72";
NET "d(5)" loc="P74";
NET "d(6)" loc="P76";
NET "d(7)" loc="P77";

NET "cms_dtack_l" loc="P79";
NET "dsp_rd_cs_l" loc="P81";
NET "dsp_wr_cs_l" loc="P82";
NET "dav_cs_l" loc="P16";
NET "dsp_rst_cs_l" loc="P15";
NET "cms1_6_cs_l" loc="P90";
NET "cms7_12_cs_l" loc="P91";
NET "joy_cs_l" loc="P14";
NET "ior_l" loc="P12";
NET "iow_l" loc="P11";
NET "ym_cs_l" loc="P13";
NET "latched_a0" loc="P9";

NET "bufen_l" loc="P93";
NET "bufdir" loc="P92";

NET "chreset" loc="P99";

NET "preempt_l" loc="P41";
NET "burst_l" loc="P40";
NET "arb(0)" loc="P39";
NET "arb(1)" loc="P37";
NET "arb(2)" loc="P36";
NET "arb(3)" loc="P35";
NET "tc_l" loc="P25";
NET "dreq" loc="P94";
NET "dack_l" loc="P10";

NET "irq_2" loc="P33";
NET "irq_3" loc="P32";
NET "irq_5" loc="P30";
NET "irq_7" loc="P29";
NET "irq_in" loc="P95";

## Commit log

2020-11-29 Fix path to STL files
2020-12-03 Add info on bracket screws
2020-12-07 Combine R41 into R26,R39 line item
    [SnarkBarkerMCA.csv, SnarkBarkerMCA.sch]
2021-06-06 Logic chip update
    [SnarkBarkerMCA.csv, SnarkBarkerMCA.sch]

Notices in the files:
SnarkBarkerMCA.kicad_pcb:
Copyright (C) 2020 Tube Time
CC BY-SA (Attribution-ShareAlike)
